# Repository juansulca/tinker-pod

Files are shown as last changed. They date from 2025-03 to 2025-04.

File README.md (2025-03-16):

# TinkerPod

Open-Source | DIY | Multitool | Modular | Extendable

The TinkerPod is an Open-Source hardware platform designed to appeal to makers, creative coders,
and designers by providing a hackable and customizable hardware. Inspired by the evolution of
multitools and influenced by contemporary devices like the Flipper Zero and SQRT,
this project explores the application of critical making, and personal fabrication to Open-Source hardware.
The TinkerPod is an ideal hardware platform for designers and makers to explore, learn, modify and extend; make it your own!

## Versions

The TinkerPod was designed to have 3 versions. All the versions are currently supported.
The main difference between versions is the parts list, complexity of assembly and features.

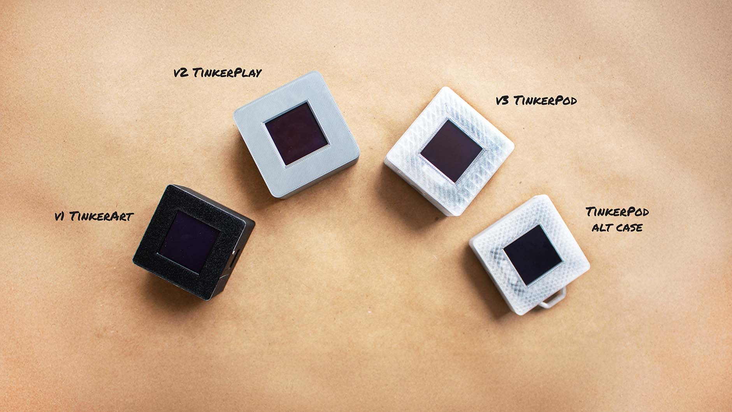
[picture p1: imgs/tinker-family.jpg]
Tinkerpod family photo


- [v1 TinkerArt](v1/): This version offers generative art functionality and can be programmed to create unique art pieces.
- [v2 TinkerPlay](v2/): This version offers a variety of games and functions, including games like pong, a timer, an etch-a-sketch inspired drawing function
  and a generative art function out of the box.
- [v3 TinkerPod](v3/): This version is an enhanced version of v2, running the same firmware but with additional features like a vibratioin sensor,
  hardware debouncing for the buttons and a fully integrated PCB.

## Hardware

This project was designed to work around the QT PY RP2040 from Adafruit. Despite this, it is possible to run the TinkerPod with
other microcontrollers with the same pinout and form factor from other manufacturers. This includes other boards from
Adafruit (QT PY line), the XIAO boards from Seeed Studio, among others.

TinkerPod v1, does not include a PCB and can be wired without tools using a tiny solderless breadboard, the display, microcontroller, and the case.

For ease of assembly starting from V2, the Screen for the TinkerPod is a 1.5" grayscale OLED display with the SSD1327 controller using a STEMMA cable. This display can be found from Adafruit and
other manufacturers but the Adafruit version is recommended due to the STEMMA cable, that reduces complexity for the assembly.

The TinkerPod v2 and v3 include PCB designs and schematics and require soldering.
A detailed assembly guide can be found along side the version files.

The hardware for this project took inspiration from the following sources:

- [Adafruit Charger BFF for QT Py](https://github.com/adafruit/Adafruit-Charger-BFF-PCB?tab=readme-ov-file#adafruit-charger-bff-for-qt-py-pcb)
- [Soldered Inkplate 2](https://github.com/SolderedElectronics/Soldered-Inkplate-2-hardware-design/tree/main)

## Firmware

All versions of the TinkerPod run on CircuitPython. The included firmware includes assets and base functionality.
You can modify the the firmware and add or change the functionality of the TinkerPod.

If you want to get started writing your own firmware and functionality, you can start with the [examples](examples/) directory.
This will provide the bassis for modifying the firmware and adding new functionality.

## Case

The case for the TinkerPod designed for 3D printing and can be printed using any FDM printer.
Printing settings are provided with each version files.

The cases for all versions were tested and printed using PLA and PETG. With the best results being
achieved with PETG on a textured plate.

Alternative cases can be found in the variants directory.

## Documentation

General guides can be found in the [docs](docs/) directory, including a simple guide to install CircuitPython and
managing the dependencies for the firmware.

## Acknowledgements

The hardware for this project took inspiration from the following sources:

- [Adafruit Charger BFF for QT Py](https://github.com/adafruit/Adafruit-Charger-BFF-PCB)
- [Soldered Inkplate 2](https://github.com/SolderedElectronics/Soldered-Inkplate-2-hardware-design/tree/main)
- [SQRT](https://ksawerykomputery.com/works/sqrt)
- [Button debounce article](https://hackaday.com/2015/12/09/embed-with-elliot-debounce-your-noisy-buttons-part-i/)

## Contributions

Contributions are welcome and appreciated. If you have any suggestions or improvements, please feel free to open an issue or submit a pull request.

## License

The TinkerPod is licensed under the following terms:

- Software: MIT License (see [LICENSE](LICENSE))
- Hardware: CERN Open Hardware Licence Version 2 - Permissive (see [LICENSE_OHL](LICENSE_OHL))
- Documentation: CC-BY-SA-4.0 (see [LICENSE_CC](LICENSE_CC))

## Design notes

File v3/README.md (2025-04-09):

# TinkerPod v3 (latest)

The latest evolution of TinkerPod delivers enhanced functionality and streamlined design through single-PCB integration. This version builds upon its predecessors, offering improved features and more robust implementation while maintaining the platform's core functionality.

The CAD and productions files for v3 con be found in the [hardware](hardware/) directory. Which is devided in:

- PCB
  - Schematic
  - PCB Layout
  - Bill of Materials
  - Gerber Files
- Case
  - Case Design
  - 3D models

The assembly instruction can be found on this page.

## v3 PCB

### Bill Of Materials

| Qty | Value | Package | Designator | Part number |
| :-- | --- | --- | --- | --- |
| 4 | .1uF, ceramic, 25V, 10%, X5R | 1210 | C1, C2, C3, C4 | KEMET - C1210X104K1RACTU |
| 2 | 10uF, ceramic, 16V, 10%, X5R | 1210 | C5, C6 | KEMET - C1210C106K3RACAUTO |
| 1 | LED | 1206 | D1 | Broadcom - HSMG-C150 |
| 1 | Schottky Diodes, 1A, 20V | SOD-123 | D2 | onsemi - MBR120ESFT1G |
| 1 | B2B-PH-SM4-TB | B2BPHSM4TBLFSN | J1 | JST - B2BPHSM4TBLFSN |
| 4 | 1K, 1/4W, 1% | 1206 | R1, R2, R3, R4 | Vishay / Beyschlag - MCA12060C1001FP500  |
| 2 | 5.1K, 1/4W, 0.1% | 1206 | R5, R6 | Panasonic - ERA-8ARB512V |
| 1 | MCP73831T-2ACI/OT | SOT-23-5 | U2 | Microchip Technology - MCP73831T-2ACI/OT |
| 1 | DPDT | JS202011AQN | S5 | C&K - JS202011AQN |

### Assembly

1. Secure the PCB with the TP v3 label facing up.
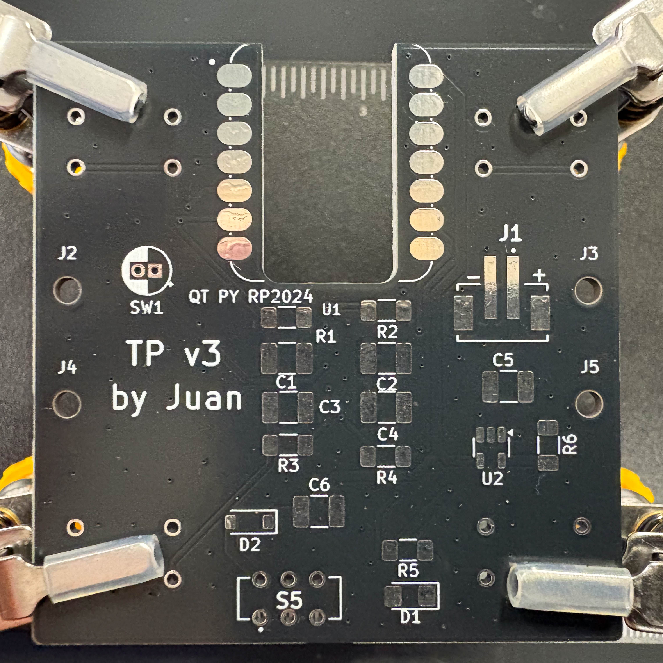
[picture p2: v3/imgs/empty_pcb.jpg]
tinkerPod PCB with label facing up
   
2. Apply paste in all the SMD pads, except for the QT PY pads, D1 and J1.
   1. Best results were achieved soldering the LED (D1) and JST (J1) connector with a soldering iron.
   2. Apply solder paste to the pads, but enough to cover the pad but not a blob bigger than the pad.
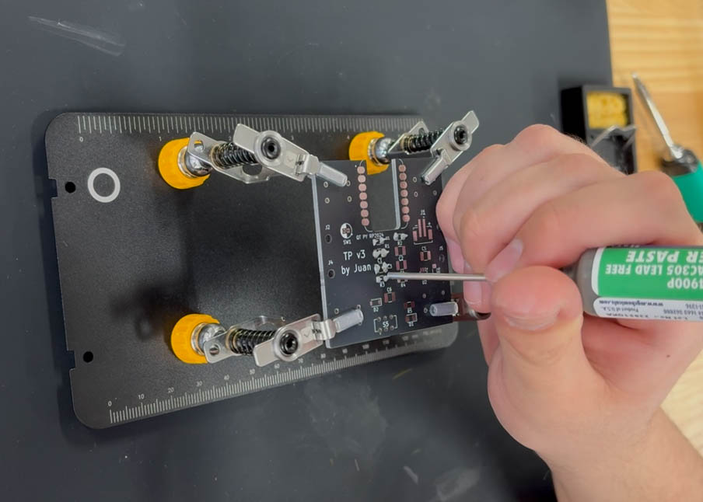
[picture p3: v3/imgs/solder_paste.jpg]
apply solder paste
      
3. Use tweezers or a tiny plastic point to remove excess solder paster.
4. Place the components that do not have polarity.
   1. Place C1, C2, C3, C4 - the .1uF capacitors.
   2. Place R1, R2, R3, R4 - 1k resistors.
   3. Place C5, C6 - 10uF capacitors.
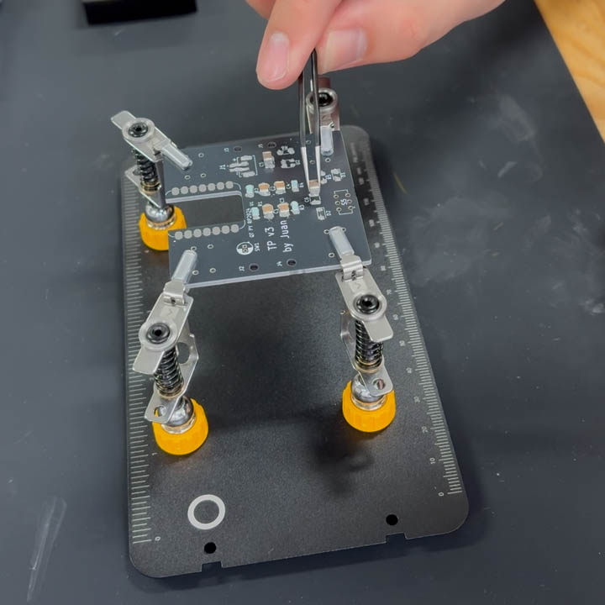
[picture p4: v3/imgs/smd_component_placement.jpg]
place smd components
      
   4. Place R5, R6 - 5.1K resistors.
5. Place the components with polarity

   1. Place D2: diode with the line facing the closed side of the rectangle
   2. Place U2: the battery charging IC

      1. The side with 3 legs should match the side with the tiny arrow

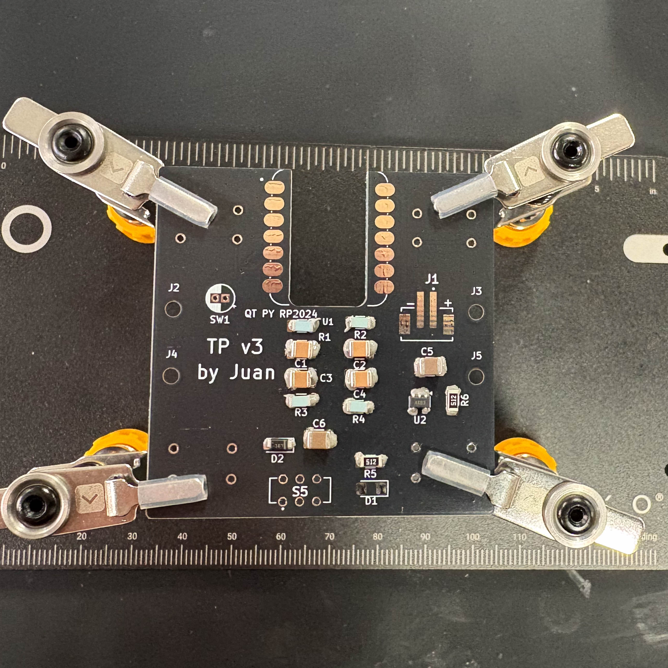
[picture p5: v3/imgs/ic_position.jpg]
battery charging IC position
      

6. Solder the components using a hot air reflow station.
   1. According to the specification of the solder paste, set the temperature, starts from the lowest recommended temperature.
   2. Start from far away with a medium to low airflow.
   3. Approach the individual components and make sure they fall correctly into place.
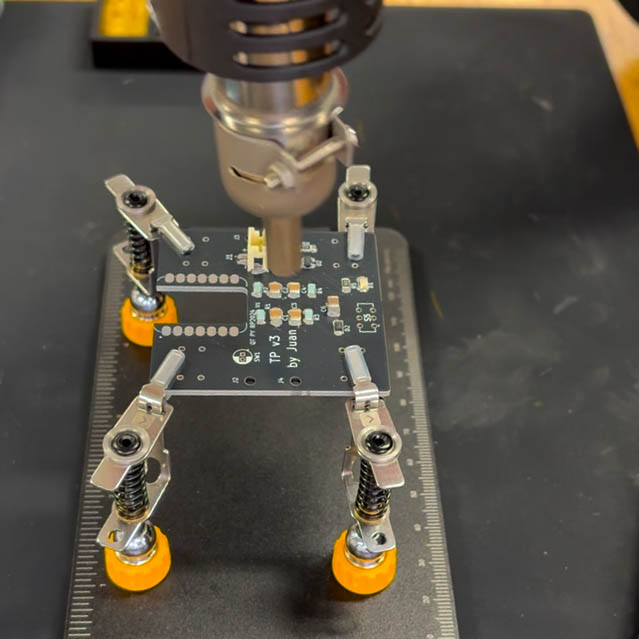
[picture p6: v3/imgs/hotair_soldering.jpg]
hot air station soldering
      
   4. After all components are soldered, visually inspect the joints, make sure the are no pads shorting and that all the paste melted. Be careful, the PCB might be hot
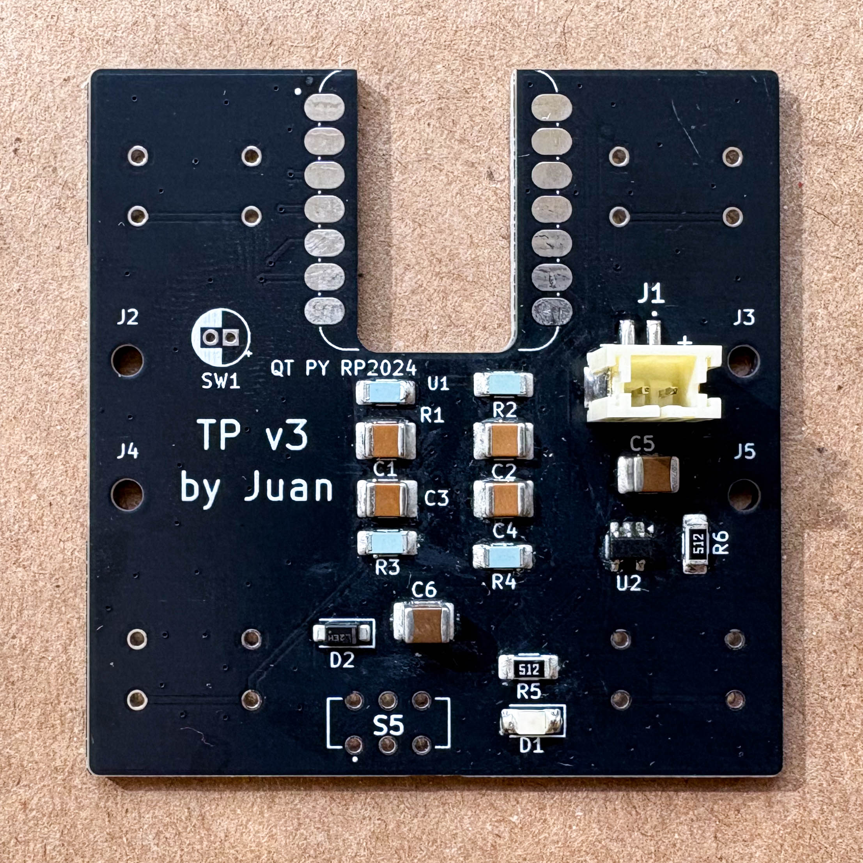
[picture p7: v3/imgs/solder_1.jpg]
PCB reference
      
   5. If there are shorting pads, retouch them with a soldering iron and some flux.
7. Solder D1 LED
   1. Check the polarity of the LED
   2. Place the LED with the Cathode (-) towards the closed side of the rectangle
   3. With the help of tweezers , solder the LED in place with a soldering iron.
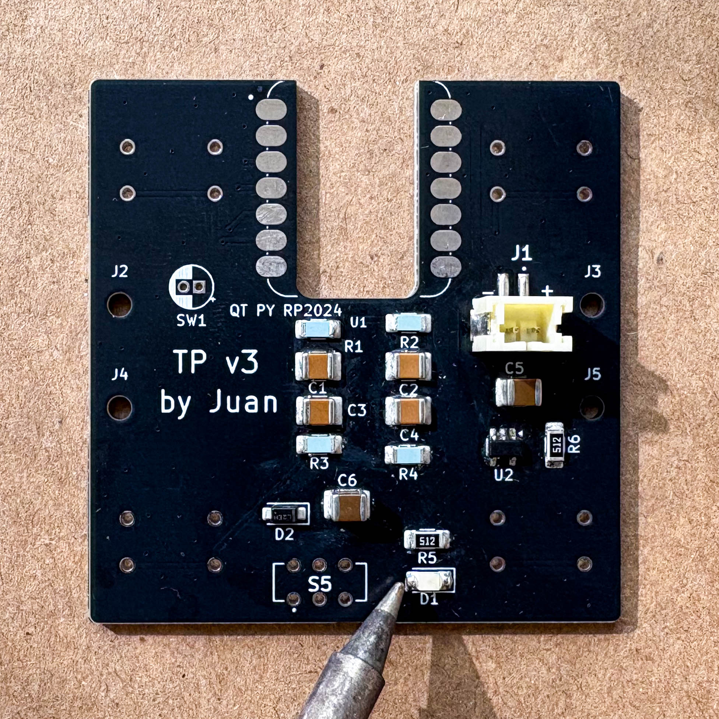
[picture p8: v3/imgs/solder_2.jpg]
Solder LED
      
8. Solder J1 JST connector.
   1. Apply some flux on the pads.
   2. Place the JST connector in place, aligning the box with the body of the connector.
   3. With the soldering iron carefully solder one of the legs of the connector.
   4. Solder the remaining legs, not much solder is needed.
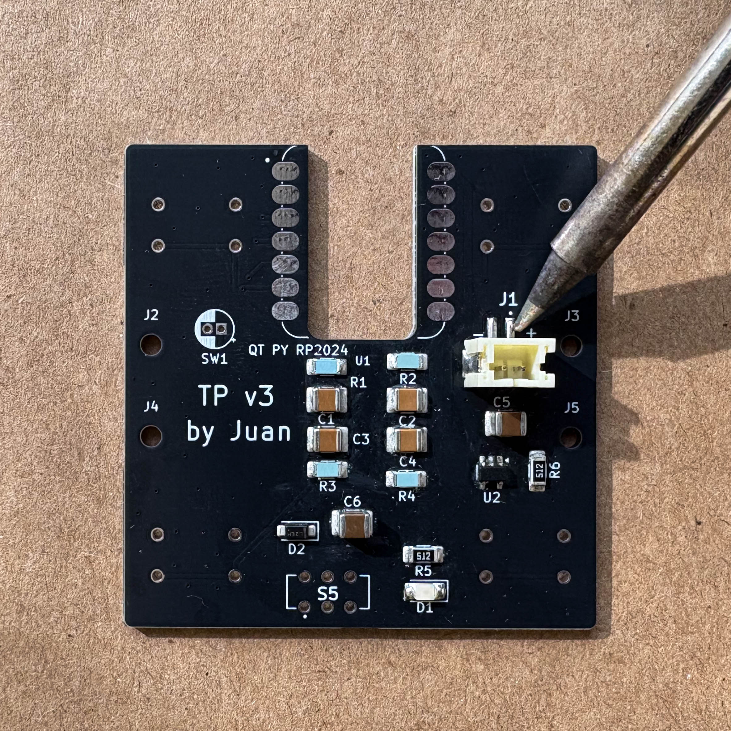
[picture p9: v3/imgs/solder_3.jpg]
Solder connector
      
9. Solder the S5 slide switch.
   1. Place the switch from the side. (TP v3 side)
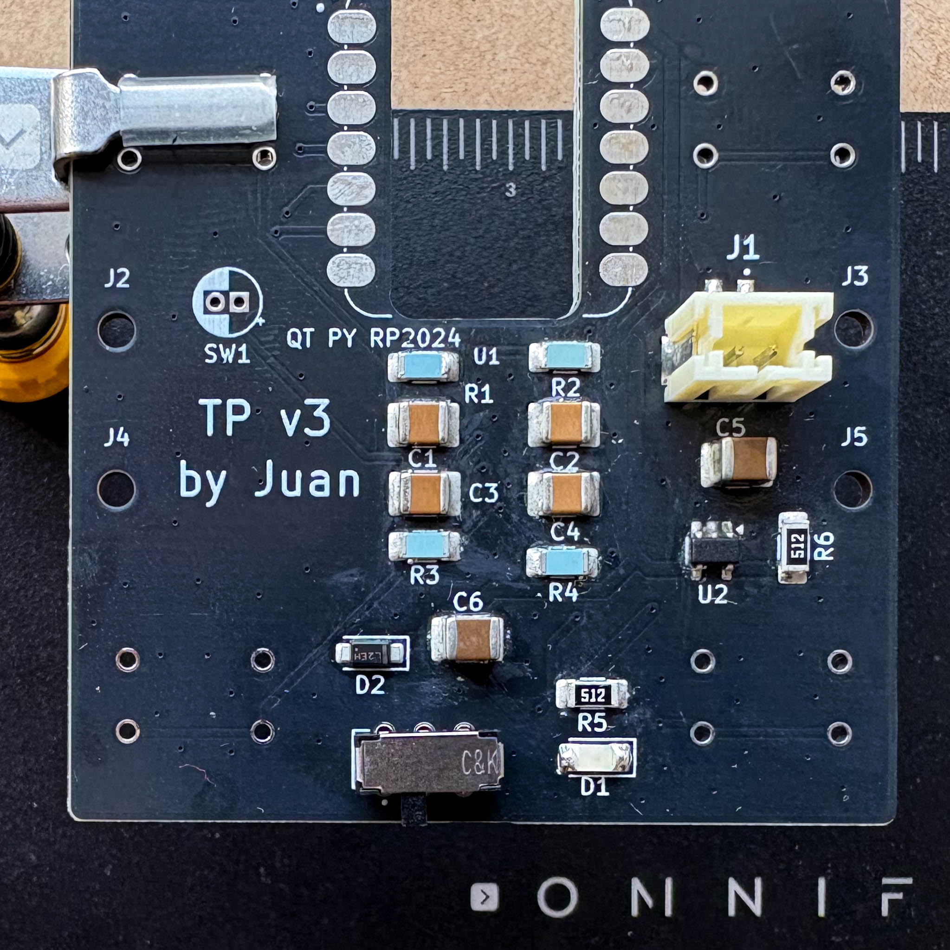
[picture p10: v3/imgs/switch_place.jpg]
placing switch
      
   2. Flip The PCB (Tinkerpod pixelated logo up)
   3. Solder the six pins.
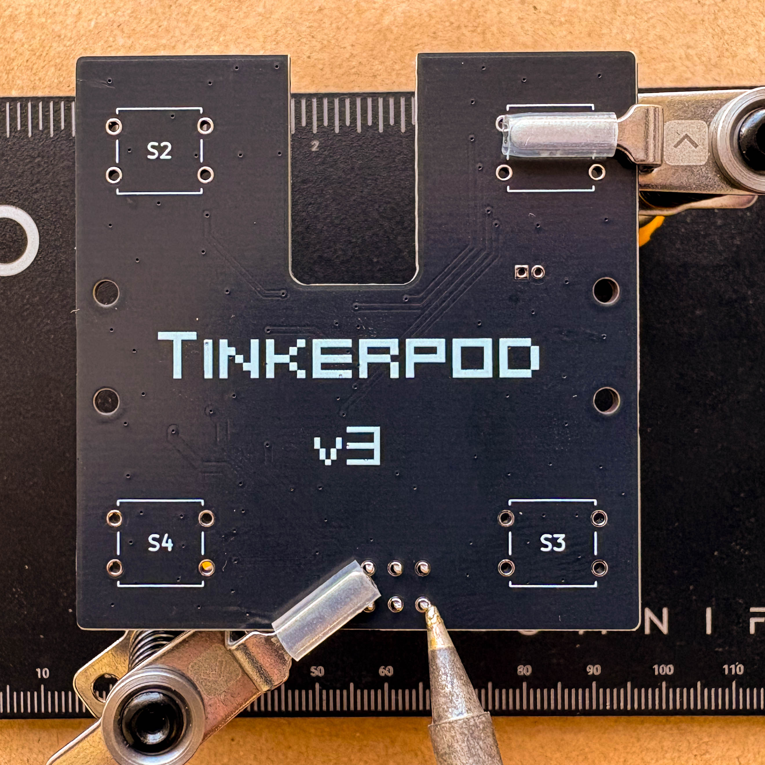
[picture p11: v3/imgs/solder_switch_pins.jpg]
Solder solder switch
      
10. The PCB assembly will continue in the next section.

## Parts List

| Item | Quantity | Description |
| --- | --- | --- |
| Adafruit QT PY RP2040 | 1 | Can be replaced with XIAO pinout boards |
| Adafruit 1.5" Gray scale OLED | 1 | SSD1327 driver chip, SPI/I2C interface  |
| TinkerPod v3 PCB | 1 | |
| STEMMA QT/Qwiic cable | 1 | 50mm long |
| Push buttons | 4 | 8mm rubber dome push buttons |
| Threaded Inserts | 8 | |
| M2 machine screws | 8 | M2 size bolts (4mm x2, 6mm x6) |
| TinkerPod v2 3D printed case  | 1 | |

## Assembly

1. Flash circuit python on the QT PY RP2040.
   1. Open the official [site](https://circuitpython.org/board/adafruit_qtpy_rp2040/) and download the latest version of circuit python.
   2. While holding the _boot_ button in the QT PY, plug it into a computer using the USB-C cable. Different version of the QT PY might need a different button to access bootloader mode, please check the official [docs](https://learn.adafruit.com/welcome-to-circuitpython/installing-circuitpython) for the specific board.
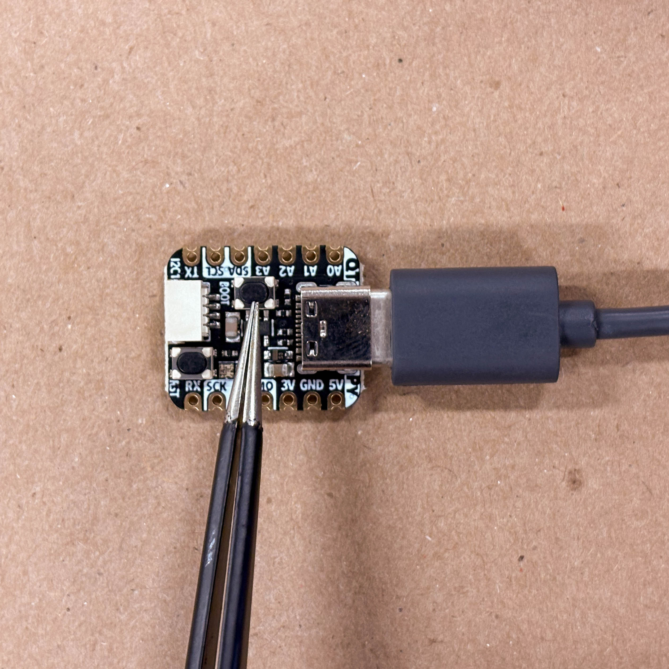
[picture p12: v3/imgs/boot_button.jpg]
boot button location
      
   3. The device should appears mounted in the OS as **RPI-RP2**, this might be different for other boards other than the RP2040 board.
   4. Drag and drop the `.UF2` file (downloaded in step 1) to the `RPI-RP2` boot drive.
   5. After a couple of seconds the onboard neopixel (LED) will flash and a new drive will appear in the computer, this time it should be called **CIRCUITPY**.
   6. ⚠️ Always eject the device before unplugging the cable.
2. Solder the QT PY to the PCB.
   1. Place the PCB with the pixelated Tinkerpod logo facing down. The **TP v3** should be visible.
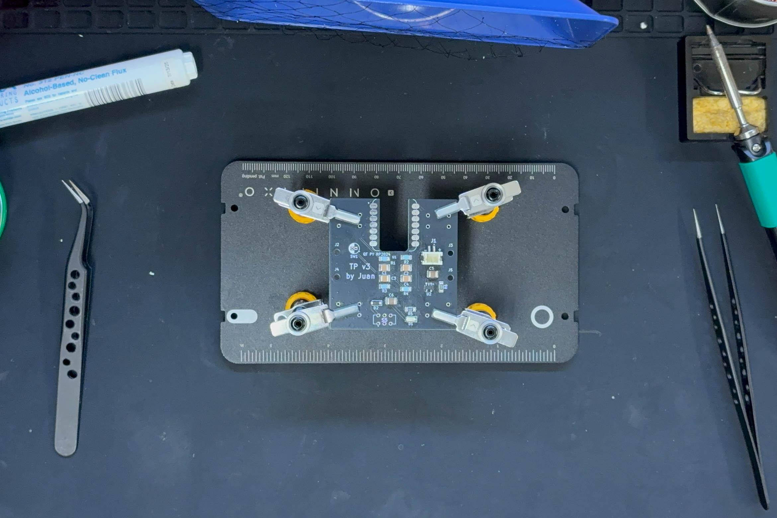
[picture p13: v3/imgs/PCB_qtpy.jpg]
Place qtpy on the PCB
      
   2. Carefully line up the QT PY with the PCB, in the `QT PY RP2040` space. The pads can be identified for the cutout in the middle. Make sure the USB port is pointing towards the outside of the board and the reset and boot buttons and the STEMMA connector are accessible.
   3. Solder the **14** pins, 7 on each side.
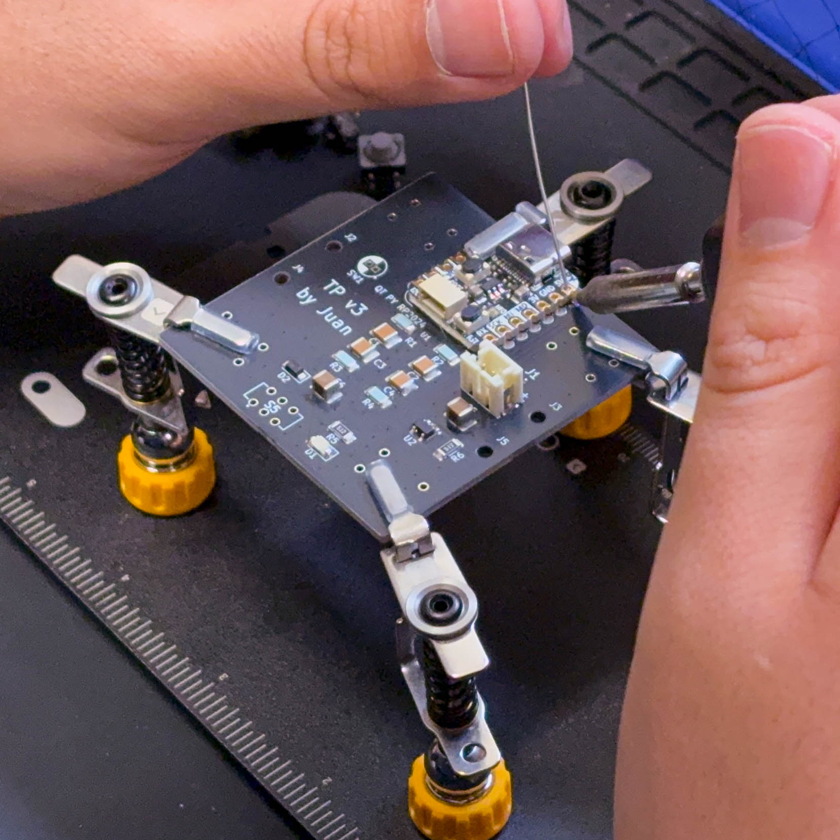
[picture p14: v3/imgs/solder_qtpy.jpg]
Solder QT PY pins
      
3. Solder the 4 buttons to the PCB.
   1. Flip the PCB (pixelated TinkerPod logo facing up).
   2. Place the buttons in the markers SW1, SW2, SW3, SW4.
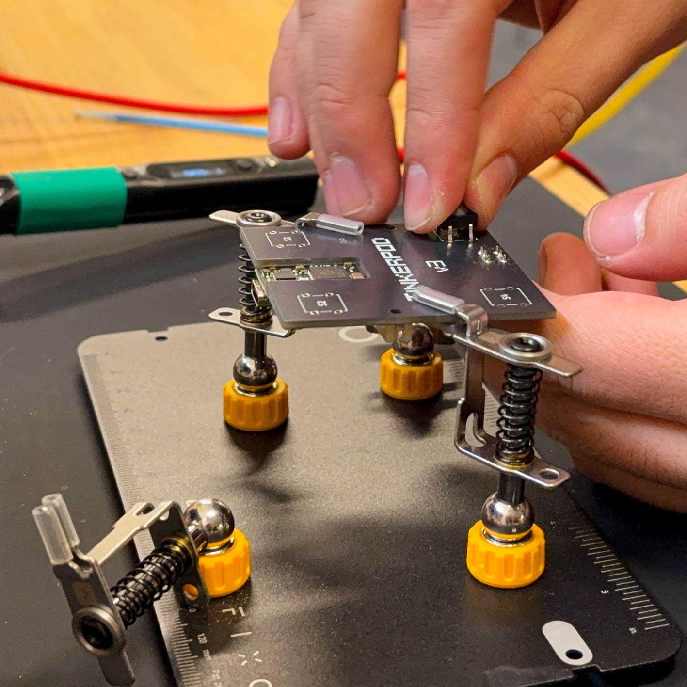
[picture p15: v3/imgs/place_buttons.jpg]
Place buttons on PCB
      
   3. Flip the PCB again (pixelated Tinkerpod logo facing down).
   4. Solder all 4 pins of every push button. (16 solder joins in total).
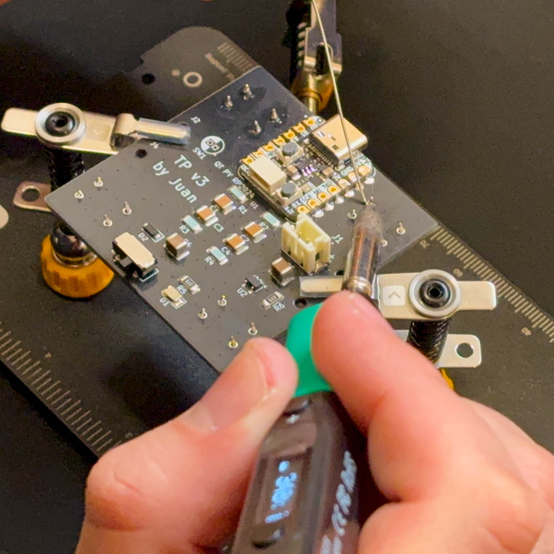
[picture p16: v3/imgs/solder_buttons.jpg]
Solder buttons pins
      
4. Solder the vibration sensor
   1. Bend the vibration sensor legs to 90 degrees.
   2. Put the vibration sensor into the SW1 slot. The vibration sensor does not have polarity.
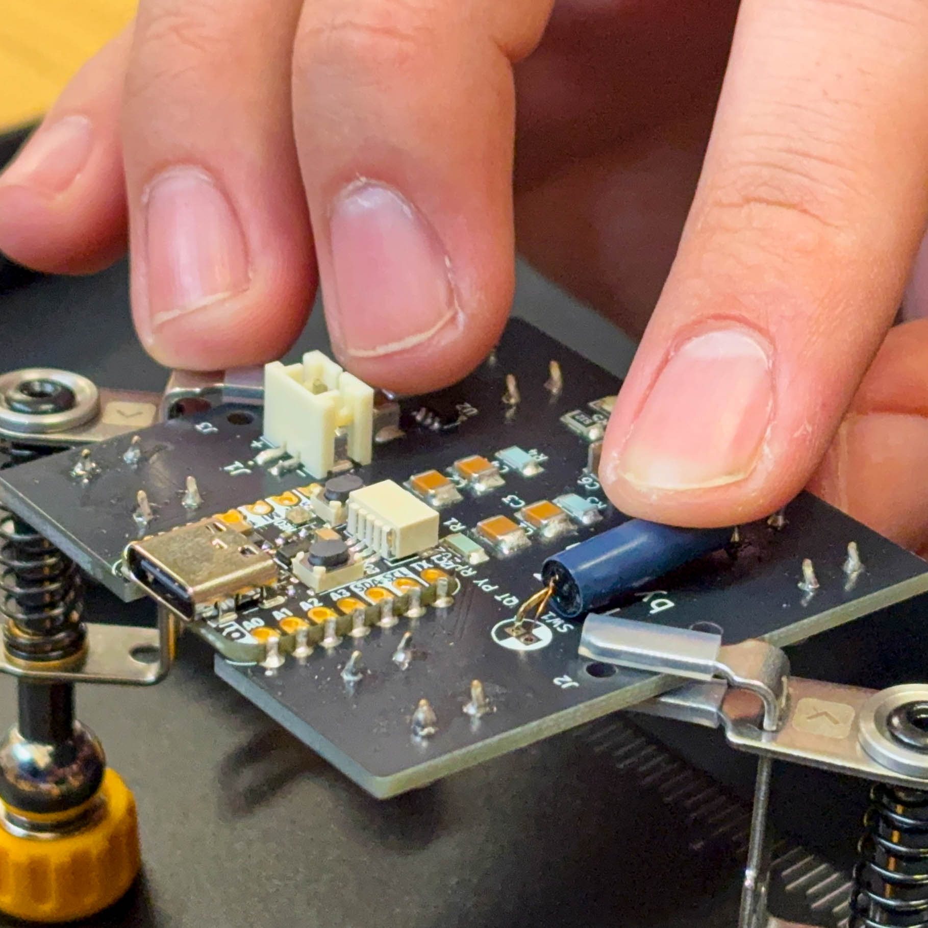
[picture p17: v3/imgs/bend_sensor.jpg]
Vibration sensor in place
      
   3. If needed use some tape to secure the vibration sensor in place while soldering.
   4. Flip the PCB (Tinkerpod logo up)
   5. Solder the two pins.
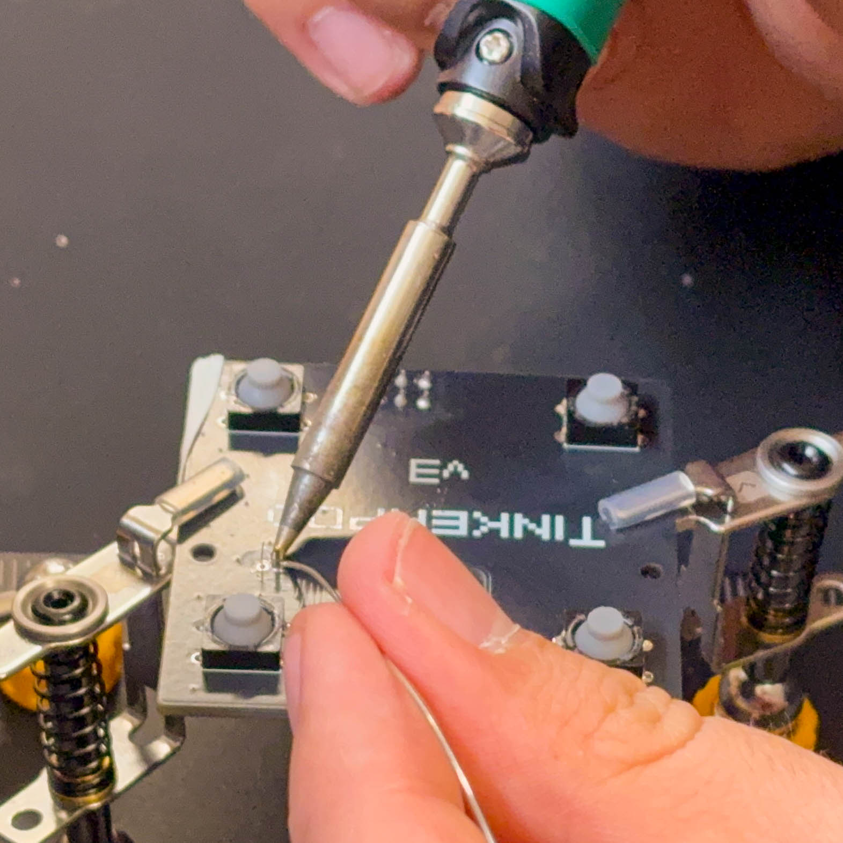
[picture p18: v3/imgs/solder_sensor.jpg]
Solder vibration sensor pins
      
   6. If the pins seem a bit long, cut them with a pair of flush cutters.
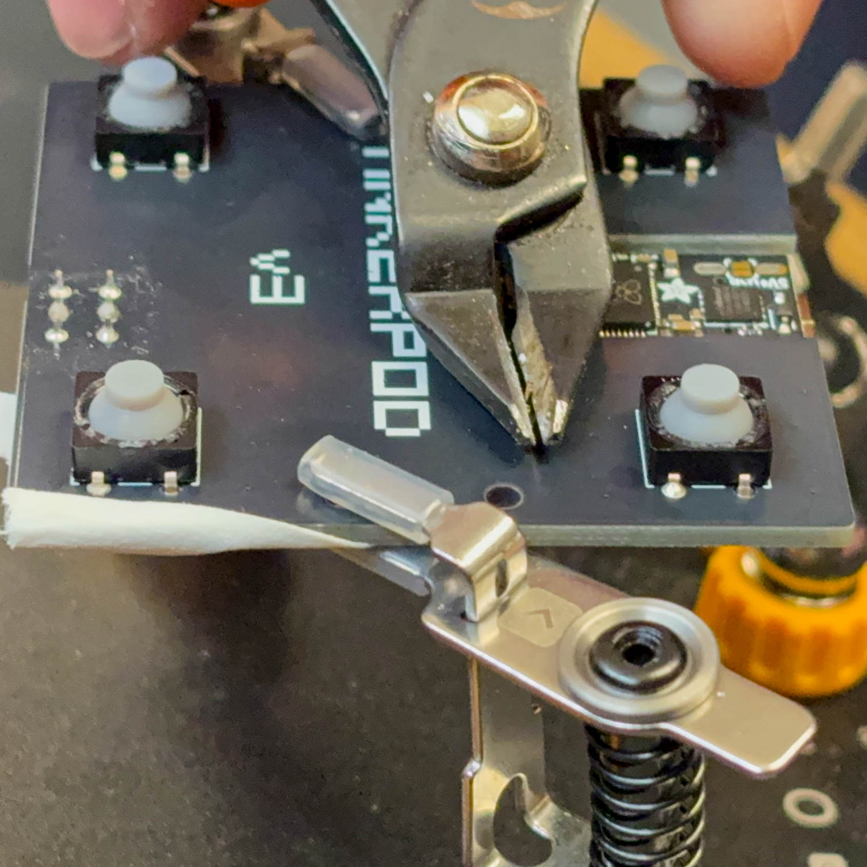
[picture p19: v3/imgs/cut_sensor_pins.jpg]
Cut sensor pins
      
5. Now is a great moment to flash firmware and test the TinkerPod before installing it into the case.
   1. Connect the STEMMA connector to the QT PY and Screen. It should slide in place without force.
   2. (Optional) Connect the battery using the JST connector in the BFF board.
   3. Download any of the TinkerPod examples from GitHub. (examples folder)
   4. Using a USB C data cable. Plug the device to the computer.
   5. Copy the content of the firmware folder (where the `code.py`file is) to the device.
   6. Do not forget to copy the `lib`directory.
   7. Alternatively install the dependencies for the firmware using `circup`.
   8. The splash screen followed by the menu should appear. Navigate the menu and use the applications by pressing the 4 buttons.
   9. A green LED should be _on_ if there is battery connected to the JST terminal.
   10. If everything works as expected, continue with the next step. If something is not working, check for cold solder joins and check that that the firmware was flashed correctly. If there is red LED flashing there is an issue with the firmware.
   11. Eject the device and unplug the USB cable.
6. Prepare the bottom case.
   1. Slide the battery bracket on the PCB.
   2. Place the PCB in place (with the USB-C port towards the hole in the enclosure) and screw it in place using the M2 machine screws.
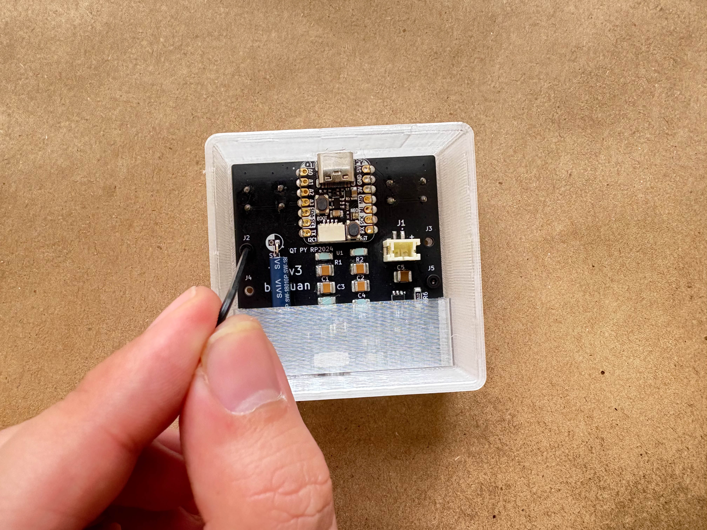
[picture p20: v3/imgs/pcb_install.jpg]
PCB installation
      
   3. Push the 3D printed on/off switch and make sure the power switch is in the _off_ position (right side).
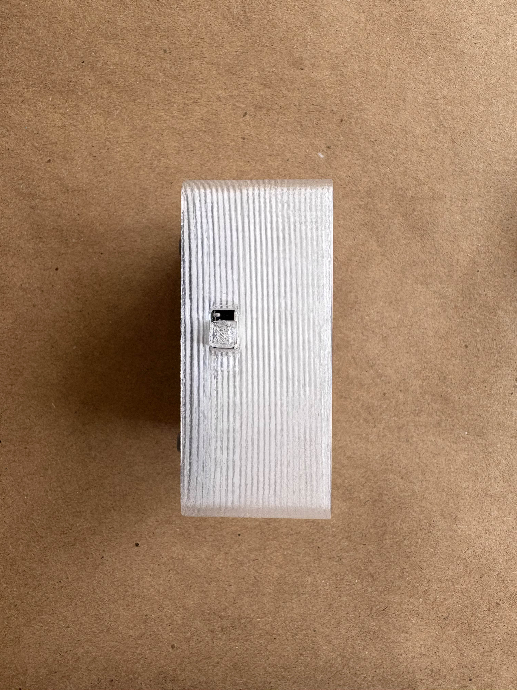
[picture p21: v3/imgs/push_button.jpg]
Push 3D printed button in place
      
7. Prepare the screen assembly
   1. Connect the STEMMA cable into the screen, it should slide in place without force.
   2. Gently place the 1.5" screen into the slot, do not apply pressure on the screen.
   3. Place the screen supports and line up the holes. The rectangular piece should go towards the top (can be placed in any orientation) and the remaining piece should go to the bottom. The bottom piece will only line up one way, with the legs pointing to the top.
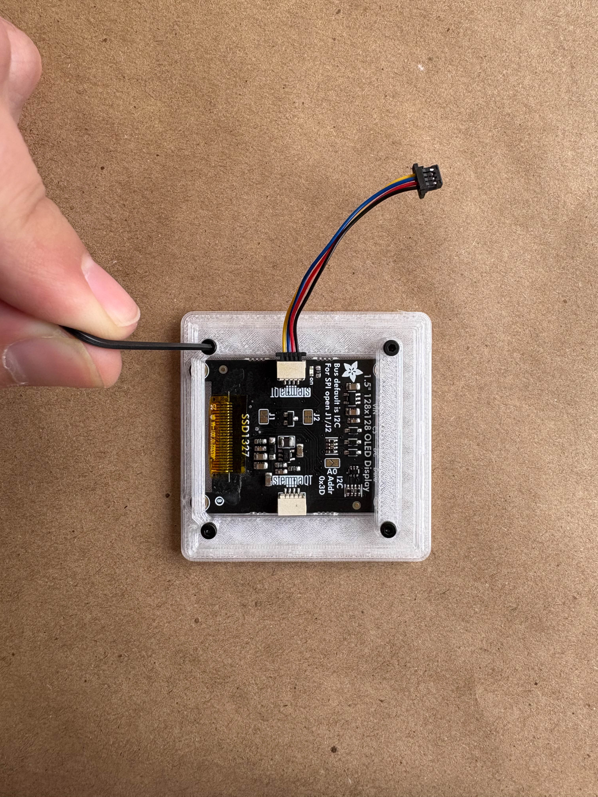
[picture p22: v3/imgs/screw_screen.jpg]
Screw screen supports in place
      
   4. Screw the supports to the top enclosure, tighten the screws until there is some resistance. Do not over tighten the screws.
   5. The screen might have some play, this is expected. And some gaps might be visible from the front side, which is also expected.
8. Closing the enclosure.
   1. Plug the other side of the STEMMA connector to the QT PY.
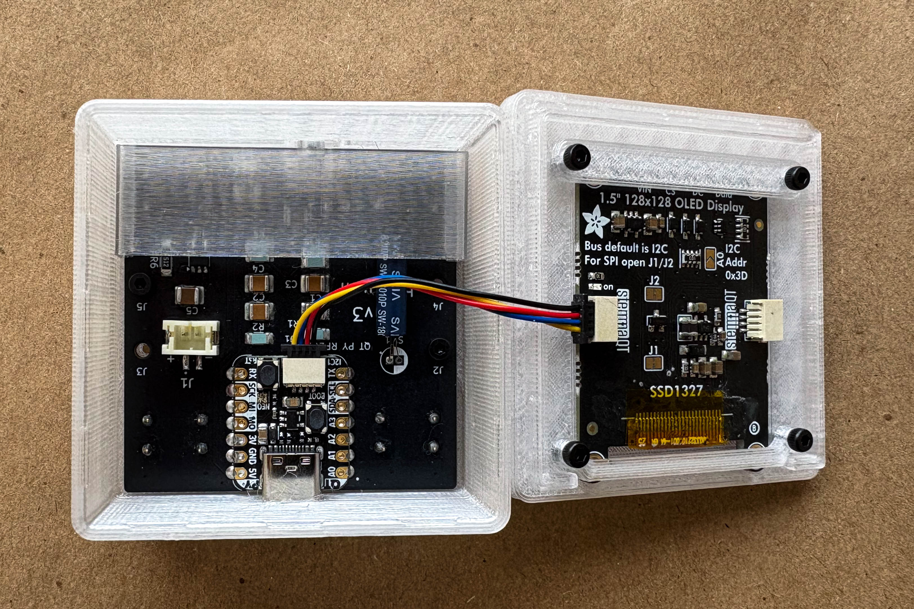
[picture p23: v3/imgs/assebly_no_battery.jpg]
Plug in STEMMA connector
      
   2. Plug in the battery.
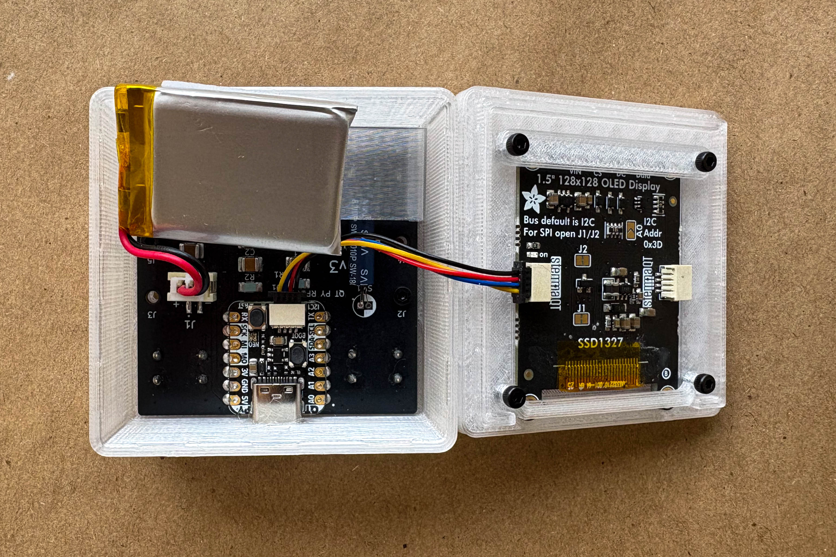
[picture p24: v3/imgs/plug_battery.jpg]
Plug in the battery
      
   3. Secure the battery using the battery bracket and some double-sided tape.
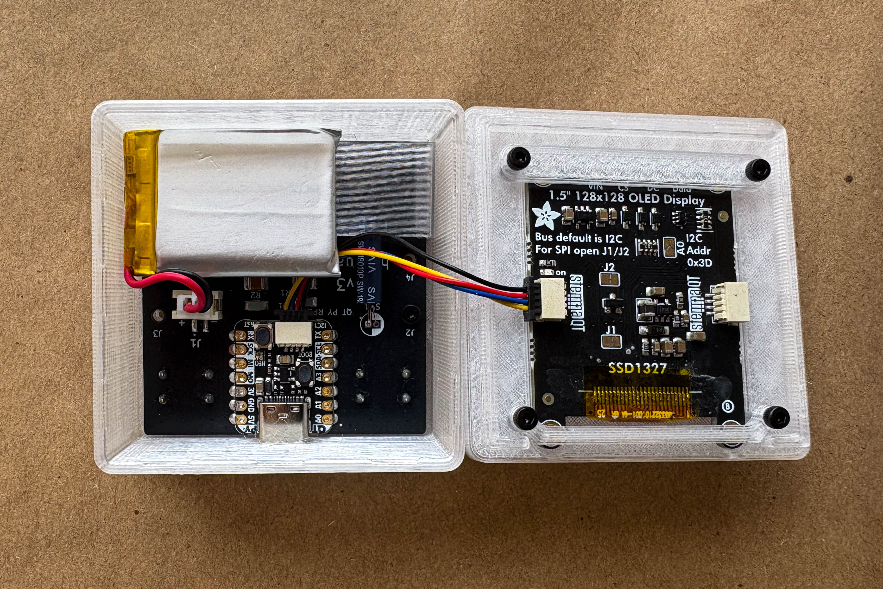
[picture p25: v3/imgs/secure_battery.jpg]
Secure battery with double sided tape
      
   4. Close the enclosure
9. Turn on your device
10. Happy Tinkering!
    Final device

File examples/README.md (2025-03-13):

# Tinker pod examples

## Introduction

This repository contains examples of using the Tinker pod in various scenarios.
Each example is designed to demonstrate a specific feature or functionality of the Tinker pod.
All these examples are related to the implementation of the Tinker pod firmware. By following these examples,
you can learn the basics of the Tinker pod to create interactive and dynamic applications.

## Structure

- **examples/**: This directory contains various examples demonstrating the usage of the Tinker pod.
  Each directory contains a README.md file that explains the purpose of the example and provides instructions on how to run it,
  the dependencies required to run the example, and the schematic.

- Start with the [screen](screen/) example, that goes over a simple screen setup and displaying text.
- The [button](button/) example, a button for the tinker pod is set up and button event handling is demonstrated.
- The [draw](draw/) example, showcase how to setup a canvas and programatically draw on the screen.
- The [animation](animation/) example, demonstrate how to move elements on the screen every frame.

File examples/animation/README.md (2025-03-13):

# Animation Example

For this example, you can use the tinker pod v2 or v3 PCB or the breadboard option from v1.

## Parts

| Part | Quantity |
| --- | --- |
| Adafruit QT PY RP2040 | 1 |
| 1.5" Gray scale OLED | 1 |
| STEMMA QT/Qwiic cable | 1 |
| Tiny breadboard (Optional) | 1 |

## Schematic

Gently connect the STEMMA QT/Qwiic cable to the Adafruit QT PY RP2040 and the 1.5" Gray scale OLED.

> Optionally you can follow the wiring diagram from v1 to use a waveshare screen.

Wiring Diagram

## Flashing CircuitPython

If you have not already installed CircuitPython, follow the guide found [here](/docs/install-circuitpython.md)

## Dependencies

Ensure this dependencies are present in the `lib` folder on the microcontroller:

- Adafruit CircuitPython firmware for the supported boards:
  https://github.com/adafruit/circuitpython/releases
- Adafruit CircuitPython SSD1327 driver:
  https://github.com/adafruit/Adafruit_CircuitPython_SSD1327
- Adafruit CircuitPython Display Text library:
  https://github.com/adafruit/Adafruit_CircuitPython_Display_Shapes

A tutorial for installing dependencies can be found [here](/docs/install-dependencies.md)

## Running the example

To run the example, follow these steps:

1. Connect the microcontroller to a computer using a USB-C cable.
2. Copye the `code.py` file from this folder to the `CIRCUITPY` drive.
3. The QT PY should soft reboot and run the code.

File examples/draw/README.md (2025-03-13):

# Draw Example

For this example, you can use the tinker pod v2 or v3 PCB or the breadboard option from v1.

## Parts

| Part | Quantity |
| --- | --- |
| Adafruit QT PY RP2040 | 1 |
| 1.5" Gray scale OLED | 1 |
| STEMMA QT/Qwiic cable | 1 |
| Tiny breadboard (Optional) | 1 |

## Schematic

Gently connect the STEMMA QT/Qwiic cable to the Adafruit QT PY RP2040 and the 1.5" Gray scale OLED.

> Optionally you can follow the wiring diagram from v1 to use a waveshare screen.

Wiring Diagram

## Flashing CircuitPython

If you have not already installed CircuitPython, follow the guide found [here](/docs/install-circuitpython.md)

## Dependencies

Ensure this dependencies are present in the `lib` folder on the microcontroller:

- Adafruit CircuitPython firmware for the supported boards:
  https://github.com/adafruit/circuitpython/releases
- Adafruit CircuitPython SSD1327 driver:
  https://github.com/adafruit/Adafruit_CircuitPython_SSD1327

A tutorial for installing dependencies can be found [here](/docs/install-dependencies.md)

## Running the example

To run the example, follow these steps:

1. Connect the microcontroller to a computer using a USB-C cable.
2. Copye the `code.py` file from this folder to the `CIRCUITPY` drive.
3. The QT PY should soft reboot and run the code.

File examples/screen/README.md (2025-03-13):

# Screen Example

For this example, you can use the tinker pod v2 or v3 PCB or the breadboard option from v1.

## Parts

| Part | Quantity |
| --- | --- |
| Adafruit QT PY RP2040 | 1 |
| 1.5" Gray scale OLED | 1 |
| STEMMA QT/Qwiic cable | 1 |
| Tiny breadboard (Optional) | 1 |

## Schematic

Gently connect the STEMMA QT/Qwiic cable to the Adafruit QT PY RP2040 and the 1.5" Gray scale OLED.

> Optionally you can follow the wiring diagram from v1 to use a waveshare screen.

Wiring Diagram

## Flashing CircuitPython

If you have not already installed CircuitPython, follow the guide found [here](/docs/install-circuitpython.md)

## Dependencies

Ensure this dependencies are present in the `lib` folder on your microcontroller:

- Adafruit CircuitPython firmware for the supported boards:
  https://github.com/adafruit/circuitpython/releases
- Adafruit CircuitPython SSD1327 driver:
  https://github.com/adafruit/Adafruit_CircuitPython_SSD1327
- Adafruit CircuitPython Display Text library:
  https://github.com/adafruit/Adafruit_CircuitPython_Display_Text

A tutorial for installing dependencies can be found [here](/docs/install-dependencies.md)

## Running the example

To run the example, follow these steps:

1. Connect the microcontroller to a computer using a USB-C cable.
2. Copye the `code.py` file from this folder to the `CIRCUITPY` drive.
3. The QT PY should soft reboot and run the code.

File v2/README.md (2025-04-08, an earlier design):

# TinkerPod v2

TinkerPod v2 is a more advanced version of the tinkerpod. This version includes 4 buttons and an optional LiIon charger and battery.
This version can be powered using a USB-C cable with a powerbank, phone or USB-C charger.
The firmware included with this version includes more applications and a application menu.

## Parts List

| Item | Quantity | Description |
| --- | --- | --- |
| Adafruit QT PY RP2040 | 1 | Can be replaced with XIAO pinout boards |
| Adafruit 1.5" Gray scale OLED | 1 | SSD1327 driver chip, SPI/I2C interface |
| TinkerPod v2 PCB | 1 | |
| STEMMA QT/Qwiic cable | 1 | 50mm long |
| Push buttons | 4 | 8mm rubber dome push buttons |
| Adafruit LiIon Charger BFF Add-On | 1 | (Optional battery powered) |
| Lithium Ion Polymer Battery | 1 | (Optional battery powered) 3.7v – 420mAh single cell |
| Threaded Inserts | 8 | |
| M2 machine screws | 8 | M2 size bolts (4mm x2, 6mm x6) |
| TinkerPod v2 3D printed case | 1 | |

## Required tools:

| Item | Description |
| --- | --- |
| Soldering Iron | Preferably one with a fine tip |
| Solder | Rosin core, preferably thin |
| Flux | Paste or pen |
| Hex key | Or screw driver depending on the screws |
| Twezzers | (optional) |
| USB-C cable | USB C **data** cable (USB C to C/A) |

## Assembly

1. Flash circuit python on the QT PY RP2040.
   1. Open the official [site](https://circuitpython.org/board/adafruit_qtpy_rp2040/) and download the latest version of CircuitPython.
   2. While holding the _boot_ button in the QT PY, plug it into a computer using the USB-C cable. Different version of the QT PY might need a different button to access bootloader mode, please check the official [docs](https://learn.adafruit.com/welcome-to-circuitpython/installing-circuitpython) for the specific board.
      boot button location
   3. The device should appears mounted in the OS as **RPI-RP2**, this might be different for other boards other than the RP2040 board.
   4. Drag and drop the `.UF2` file (downloaded in step 1) to the `RPI-RP2` boot drive.
   5. After a couple of seconds the onboard neopixel (LED) will flash and a new drive will appear in the computer, this time it should be called **CIRCUITPY**.
   6. ⚠️ Always eject the device before unplugging the cable.
2. (Optional) Solder the LiIon Charger BFF to the PCB.
   1. Place the PCB donut side down. The **TinkerPod** and **v2** silkscreen labels should be visible.
   2. Carefully line up the BFF with the PCB, in the M2 space, also marked as BFF LiPo charger. The JST connector (white box) should be facing the **v2** text on the PCB.
      bff line up
   3. Solder all the pads. take extra care on the 5V and GND pads.
      solder bff pads
3. Solder the QT PY to the PCB.
   1. Place the PCB donut side down. The **TinkerPod** and **v2** silkscreen labels should be visible.
   2. Carefully line up the QT PY with the PCB, in the `M1` space also marked on the side as `QT PY RP2040`. The pads can be identified for the cutout in the middle. Make sure the USB port is pointing towards the outside of the board and the reset and boot buttons and the STEMMA connector are accessible.
      QT PY lineup
   3. Solder the **14** pins, 7 on each side.
      QT PY solder pins
4. Solder the 4 buttons to the PCB.
   1. After completing steps 2 and 3, flip the PCB (Donut side up).
      PCB donut side up
   2. Place the buttons in the markers SW1, SW2, SW3, SW4.
      button placement
   3. Flip the PCB again (Donut side down).
   4. Solder all 4 pins of every push button. (16 solder joins in total).
      solder pins for button
5. Now is a great moment to flash the firmware and test the TinkerPod before installing it into the case.
   1. Connect the STEMMA connector to the QT PY and Screen. It should slide in place without force.
      connect STEMMA connector to QT PY
   2. (Optional) Connect the battery using the JST connector in the BFF board.
      PCB with battery connected
   3. Download the TinkerPod firmware from GitHub. (firmware folder)
   4. Using a USB C data cable. Plug the device to the computer.
   5. Copy the content of the firmware folder (where the `code.py`file is) to the device.
   6. Remember to copy the `lib`directory.
   7. Alternatively check this project documentation for alternative installation methods.
   8. The splash screen followed by the menu should appear. Navigate the menu and use the applications by pressing the 4 buttons.
   9. The charging indicator (orange LED) in the BFF board should light up if there is a battery connected and the BFF installed.
      Test assembly with orange LED on and text on the screen
   10. If everything works as expected, continue with the next step.
       1. If something is not working:
       2. Check for cold solder joins
       3. Verify that that the firmware was flashed correctly.
       4. If there is red LED flashing there is an issue with the firmware.
   11. Eject the device and unplug the USB cable.
6. Place the 3D printed buttons in the enclosure and make sure they slide smooth.
   placing buttons
7. Prepare the bottom enclosure.
   1. Place the threaded inserts in the holes located in the top part of the enclosure.
      placing inserts
   2. Using the soldering iron push the inserts as straight as possible until they are flush with the surface of the enclosure.
      push inserts with soldering iron
   3. Place the PCB in place (with the USB-C port towards the hole in the enclosure) and screw it in place using the M2 machine screws.
   4. Make sure the power switch on the BFF board is in the _off_ position.
   5. Plug in the battery.
      battery plugged in
   6. Secure the battery using the battery bracket and some double sided tape.
8. Prepare the screen assembly
   1. Place the threaded inserts in the holes located in the top part of the enclosure.
   2. Using the soldering iron push the inserts as straight as possible until they are flush with the surface of the case.
      top enclosure inserts
   3. Connect the STEMMA cable into the screen, it should slide in place without force.
   4. Gently place the 1.5" screen into the slot, do not apply pressure on the scree.
      screen in top enclosure
   5. Place the screen supports and line up the holes. The rectangular piece should go towards the top (can be placed in any orientation) and the remaining piece should go to the bottom. The bottom piece will only line up one way, with the legs pointing to the top.
   6. Screw the supports to the top case, tighten the screws until there is some resistance. Do not over tighten the screws.
      screw screen supports
   7. The screen might have some play, this is expected. And some gaps might be visible from the front side, which is also expected.
9. Closing the case.
   1. Plug the other side of the STEMMA connector to the QT PY.
      final device assembly
   2. Using the power switch in the BFF board, turn the device _on_.
   3. Gently push the two parts of the case together.
10. Happy tinkering!
    final device assembly

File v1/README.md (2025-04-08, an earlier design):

# Tinkerpod v1

The TinkerPod v1 is the simplest version of the family. It is designed to be a basic introduction to the TinkerPod ecosystem.

## Part list

| Part | Quantity |
| --- | --- |
| Adafruit QT PY RP2040 | 1 |
| 1.5" Gray scale OLED  | 1 |
| Tiny breadboard | 1 |
| Jumper wires | 5 |

## 3D Printed Case

This version was tested with PLA and PETG.
The suggested orientation of the two parts is with the flat surfaces facing the build plate.
The print was made without supports with the following params:

| Param | Value |
| --- | ----- |
| Layer height | 0.2mm |
| Nozzle | 0.4mm |
| Infill | 20% |

The STL files can be found in the [`case/`](case/) directory.

## Firmware

The current firmware consists of the screen setup and a generative art demo.
The firmware is written in CircuitPython and works
by coping the content of the [`firmware`](firmware/) directory to the microcontroller.

### Dependencies

The firmware depends on the following libraries:

- [Adafruit CircuitPython SSD1327 driver](https://github.com/adafruit/Adafruit_CircuitPython_SSD1327)

More information about this library can be found in the official [docs](https://docs.circuitpython.org/projects/ssd1327/en/latest/)

## Assembly

1. Flash circuit python on the QT PY RP2040.

   1. Open the official [site](https://circuitpython.org/board/adafruit_qtpy_rp2040/) and download the latest version of CircuitPython.
   2. While holding the _boot_ button in the QT PY, plug it into a computer using the USB-C cable. Different version of the QT PY might need a different button to access bootloader mode, please check the official [docs](https://learn.adafruit.com/welcome-to-circuitpython/installing-circuitpython) for the specific board.
      boot button location
   3. The device should appears mounted in the OS as **RPI-RP2**. This might be different for other boards other than the RP2040 board.
   4. Drag and drop the `.UF2` file (downloaded in step 1) to the `RPI-RP2` drive.
   5. After a couple of seconds the onboard neopixel (LED) will flash and a new drive will appear in the computer, this time it should be called **CIRCUITPY**.
   6. ⚠️ Always eject the device before unplugging the cable.

2. Solder the headers to the QT PY.
   1. Position the headers in the QT PY and carefully place both the breadboard.
      header positioning
   2. Solder the headers to the microcontroller.
      header soldering
3. Place the microcontroller on the breadboard and connect the screen cable to the screen socket.
   screen connector placement
4. Connect the screen to the QT PY following this diagram:
   Tinkerpod v1 wiring diagram
5. Plug the USB-C cable to the micro controller.
   microcontroller breadboard
6. Check your file explorer for new drive called CIRCUITPY
7. Download the `firmware/` directory for this version.
8. Copy all the files from the `firmware/` directory (`code.py` and `lib/`) to the **CIRCUITPY** drive.
9. After the device restarts, look at the OLED screen which will display a generative art function.
10. Place the screen in the top part of the enclosure.
    screen in top enclosure
11. Place the breadboard in the bottom part of the enclosure.
    breadboard in enclosure and screen
12. Close the enclosure with some tape.
    final

> ⚠️ Do not unplug the device from your computer without ejecting it properly.

## Official mods

### Add interaction with a vibration sensor

To add the same vibration sensor from version 2 to the TinkerPod v1.

Follow this schematic:

vibration sensor schematic

And update the `code.py` file to use the sensor following the [button example](/examples/button).

For example:

```python
# code.py in firmware

# create the digital input for the vibration sensor on Pin A1
shake = digitalio.DigitalInOut(board.A1)
shake.direction = digitalio.Direction.INPUT
# enable pull up resistor
shake.pull = digitalio.Pull.UP

# store the shake state
was_shaken = False

while(True):
	# read the shake sensor as any other button
	if not shake.value:
		# store the shake state
		was_shaken = True

	# if the device was shaken
	if was_shaken:
		# get a random quadrant
		i = random.randint(0, 15);
		# clear the space on the screen
		clear_quadrant(i)
		# get a random draw function
		fn = random.choice(fns)
		# draw the function on the screen
		fn(i)
		# clear the shaken state
		was_shaken = False
		# wait for 0.3 seconds
		time.sleep(0.3)
```

Now the tinkerpod will react to a shake by updating the screen.

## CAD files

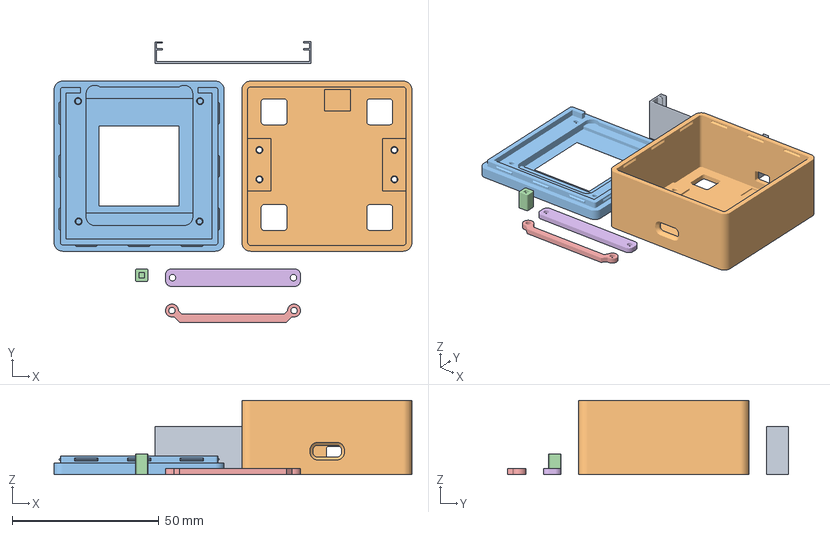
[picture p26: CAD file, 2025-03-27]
v3/case/TP_v3_case.3mf
122.0 x 95.6 x 25.2 mm
battery_bracket
lead
power_button
support_1
support_2

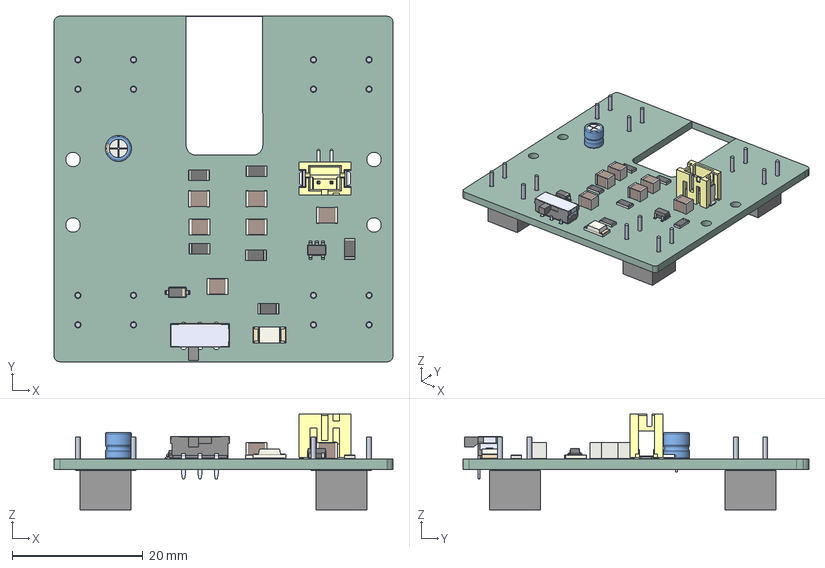
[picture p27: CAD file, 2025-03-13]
v3/hardware/tinker-pod-v3.step
51.8 x 52.8 x 14.6 mm
R_1206_3216Metric x 6
C_1210_3225Metric x 6
SOT_23_5
CP_Radial_D40mm_P150mm
LED_2010_5025Metric
D_SOD_123
JS202011AQN
B2B-PH-SM4-TB(LF)(SN)
ASSEMBLY x 4
tinker-pod-v3_PCB

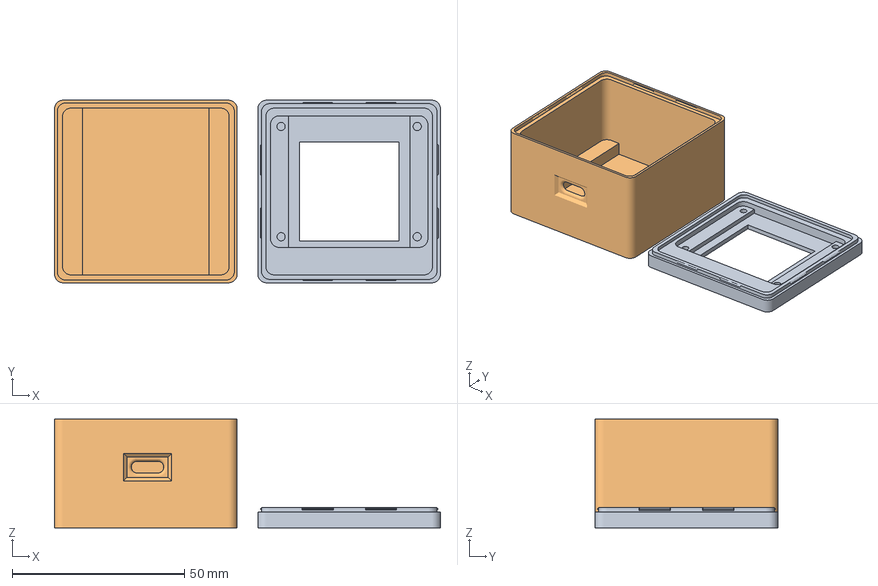
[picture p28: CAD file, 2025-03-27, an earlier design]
v1/case/TP_v1_case.3mf
112.0 x 53.0 x 31.5 mm
screen

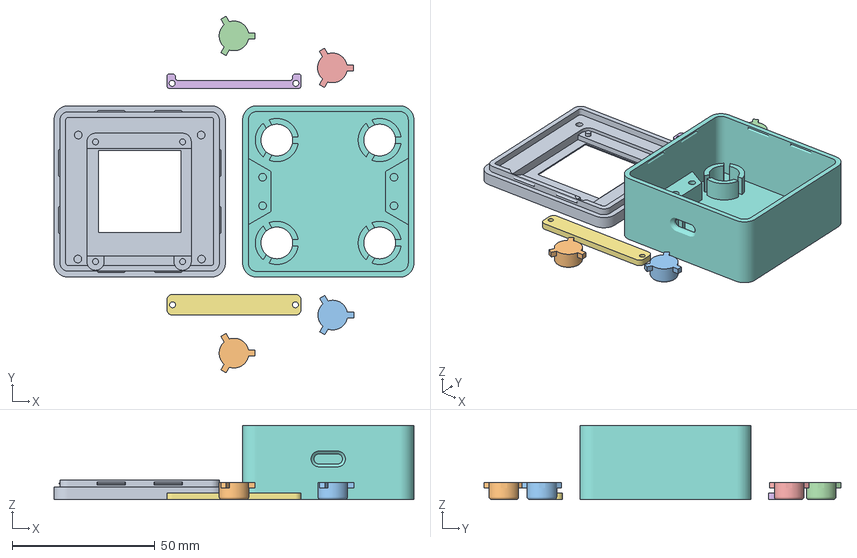
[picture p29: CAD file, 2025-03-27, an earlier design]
v2/case/TP_v2_case.3mf
126.0 x 124.8 x 26.0 mm
New_Top
Button
screen_support_1
screen_support_2
new_Bottom_v2

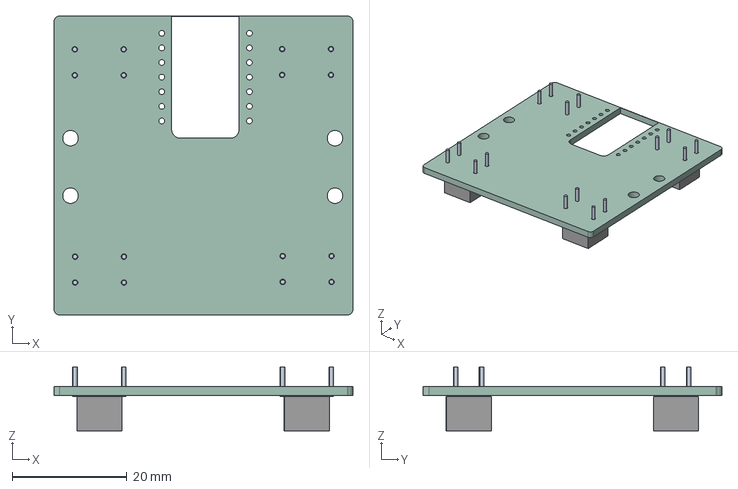
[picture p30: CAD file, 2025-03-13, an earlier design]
v2/hardware/tinker-pod-buttons.step
52.0 x 52.0 x 11.1 mm
ASSEMBLY x 4
tinker-pod-buttons_PCB

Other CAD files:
v1/case/TinkerPod_v1_case.f3d
v2/case/TP_v2_case.f3z
v3/case/TP_v3_case.f3z

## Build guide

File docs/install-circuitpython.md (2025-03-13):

# How to Install CircuitPython on Adafruit QT PY RP2040

To flash CircuitPython onto your Adafruit QT PY RP2040, follow these steps:

1. Open the official [site](https://circuitpython.org/board/adafruit_qtpy_rp2040/) and download the latest version of circuit python.
2. While holding the _boot_ button in you QT PY, plug it into your computer using the USB-C cable.
   Different version of the QT PY (the non-RP2040 variants) might need a different button to access bootloader mode,
   please check the official [docs](https://learn.adafruit.com/welcome-to-circuitpython/installing-circuitpython) for the board you are using.
3. The device should appears mounted in your OS as **RPI-RP2**, this might be different if you are not using an RP2040 board.
4. Drag and drop the `.UF2` file you downloaded in step 1 to the `RPI-RP2` boot drive.
5. After a couple of seconds some lights will flash and a new drive will appear in your computer, this time it should be called **CIRCUITPY**.
6. ⚠️ Always eject your device before removing it.
7. Your device is ready to be installed.

The official docs to install CircuitPython can be found [here](https://learn.adafruit.com/adafruit-qt-py-2040/circuitpython)

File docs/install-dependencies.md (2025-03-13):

# Install Dependencies for the Tinker Pod

The official documentation for installing dependencies in CircuitPython can be found [here](https://learn.adafruit.com/welcome-to-circuitpython/circuitpython-libraries).

## Option 1 (easy)

Copy the `lib` directory and its contents from the example or the firmware directory. to the _CIRCUITPY_ directory.

## Option 2 (harder)

Use [this](https://marketplace.visualstudio.com/items?itemName=joedevivo.vscode-circuitpython) extension from Visual Studio Code.

### How to install a dependency

1. Open the _CIRCUITPY_ directory in Visual Studio Code.
2. Use the shortcut `Ctrl+Shift+P` to open the command palette.
3. Type `CircuitPython` and select `CircuitPython: Choose CircuitPython board`.
4. Select the board, in this case `QT PY RP2040`
5. Press `Enter` to confirm the selection.
6. Use the shortcut `Ctrl+Shift+P` to open the command palette.
7. Type `CircuitPython` and select `CircuitPython: Show available libraries`.
8. Type the name of the dependency and select the option that matches the desired library.
9. Press `Enter` to confirm the selection.

## Option 3 (advanced)

Use [CircUp](https://learn.adafruit.com/keep-your-circuitpython-libraries-on-devices-up-to-date-with-circup) to install the dependencies.

1. Install and setup `circup`. Use the official guide, found [here](https://learn.adafruit.com/keep-your-circuitpython-libraries-on-devices-up-to-date-with-circup/install-circup).
2. Open the terminal
3. Use the command `circup install library-name`

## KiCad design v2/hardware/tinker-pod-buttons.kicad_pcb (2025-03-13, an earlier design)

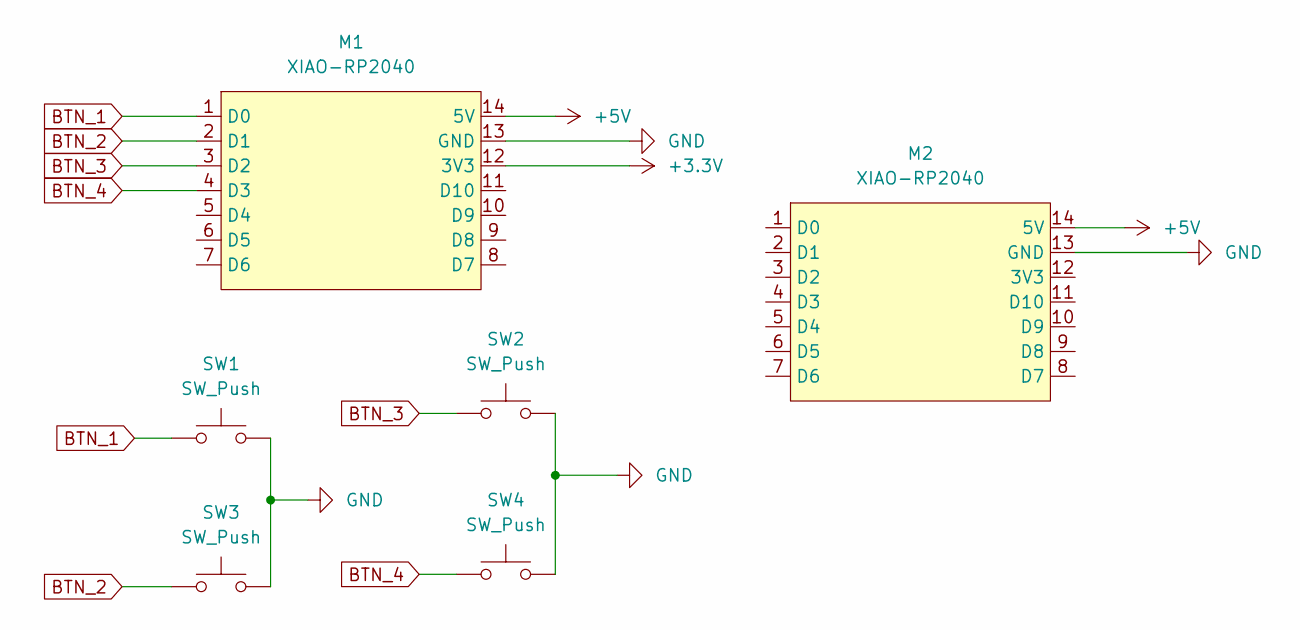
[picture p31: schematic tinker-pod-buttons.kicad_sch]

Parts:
M1: XIAO-RP2040; QTPYRP2040
M2: XIAO-RP2040; XIAO-SAMD21-RP2040-14P-2.54-21X17.8MM (Seeeduino XIAO)
SW1, SW2, SW3, SW4: SW_Push; 3101

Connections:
+3.3V: M1.12 (3V3)
+5V: M1.14 (5V), M2.14 (5V)
BTN_1: M1.1 (D0), SW1.1
BTN_2: M1.2 (D1), SW3.1
BTN_3: M1.3 (D2), SW2.1
BTN_4: M1.4 (D3), SW4.1
GND: M1.13 (GND), M2.13 (3V3), SW1.2, SW2.2, SW3.2, SW4.2

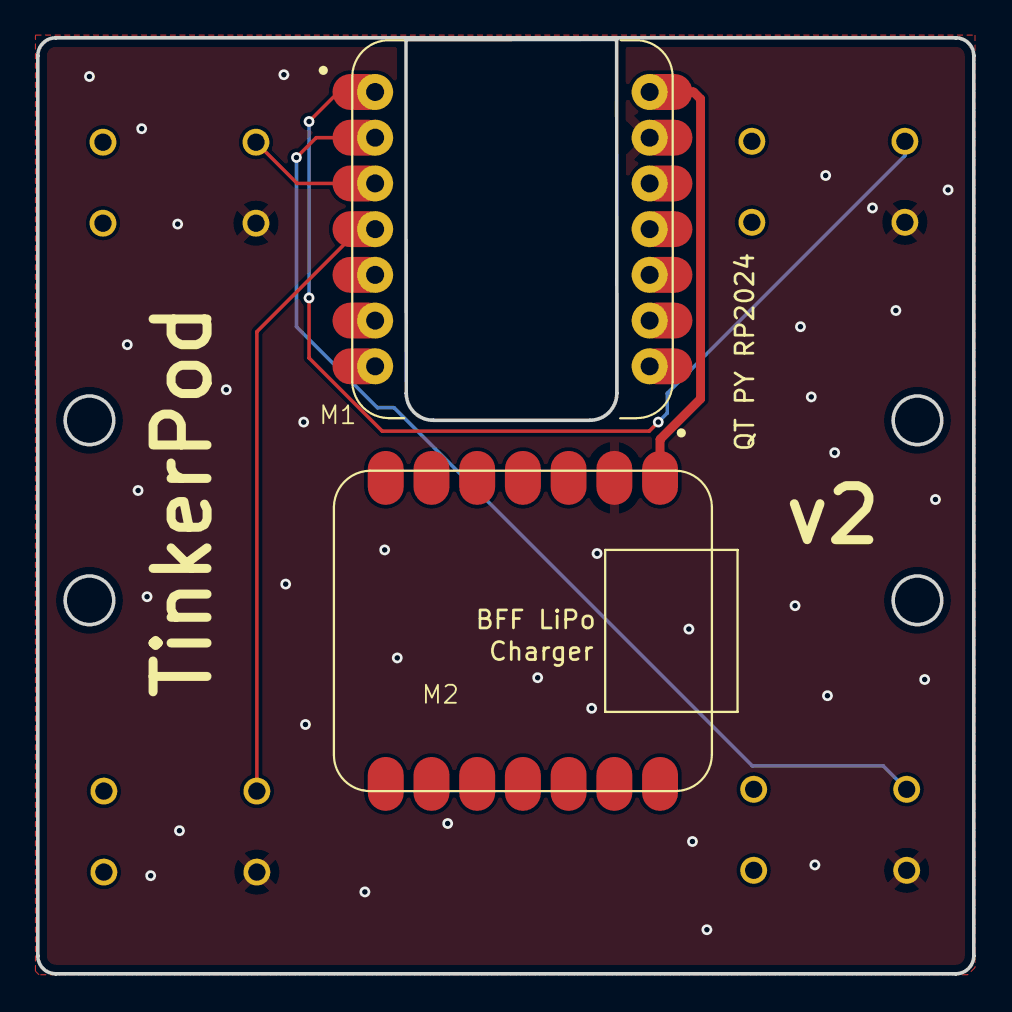
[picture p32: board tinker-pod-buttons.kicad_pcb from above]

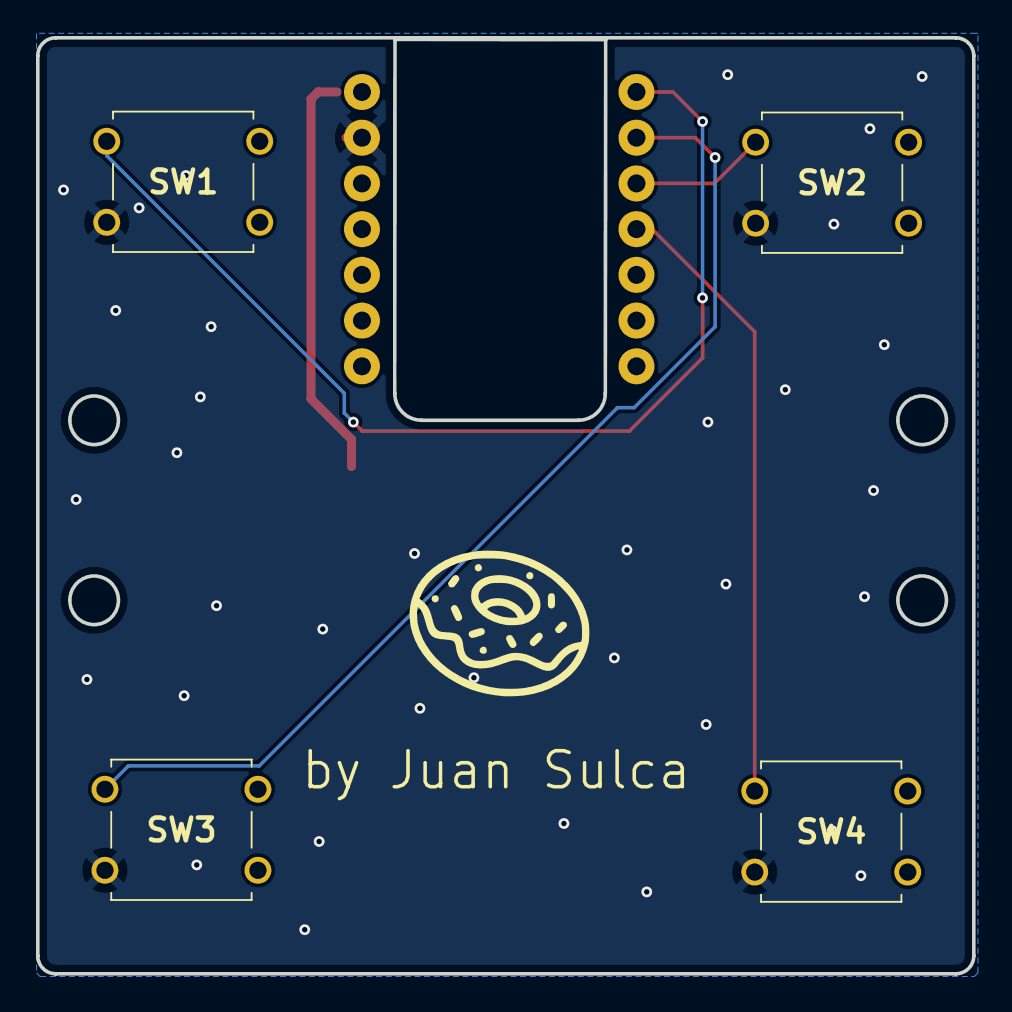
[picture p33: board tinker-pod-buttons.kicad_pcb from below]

Board: 2 copper layers, 52.0 x 52.0 mm, 6 parts (4 on the bottom side), 6 nets.

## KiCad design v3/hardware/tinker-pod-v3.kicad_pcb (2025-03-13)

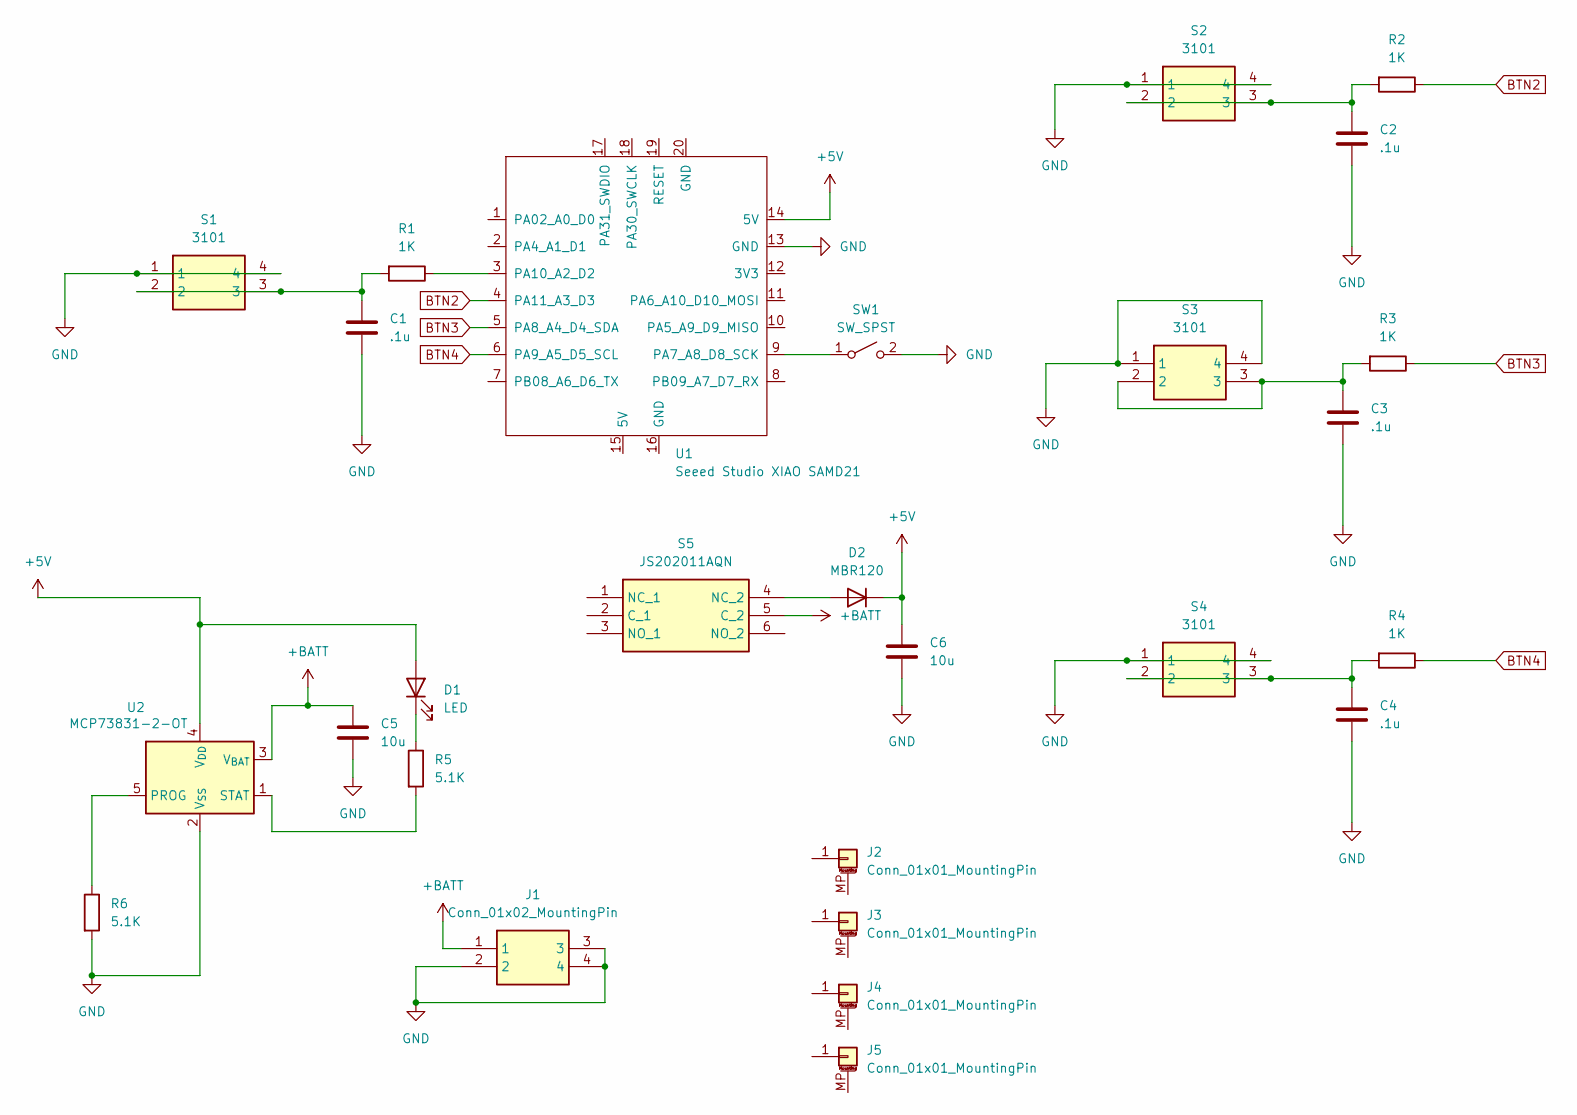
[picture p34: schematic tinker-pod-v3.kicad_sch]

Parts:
C1, C2, C3, C4: .1u; C_1210_3225Metric_Pad1.33x2.70mm_HandSolder
C5, C6: 10u; C_1210_3225Metric_Pad1.33x2.70mm_HandSolder
D1: LED; LED_1206_3216Metric_Pad1.42x1.75mm_HandSolder
D2: MBR120; D_SOD-123
J1: Conn_01x02_MountingPin; B2BPHSM4TBLFSN; Mouser Part Number N/A
J2, J3, J4, J5: Conn_01x01_MountingPin; MountingHole_2.2mm_M2
R1, R2, R3, R4: 1K; R_1206_3216Metric_Pad1.30x1.75mm_HandSolder
R5, R6: 5.1K; R_1206_3216Metric_Pad1.30x1.75mm_HandSolder
S1, S2, S3, S4: 3101; Mouser Part Number 485-3101
S5: JS202011AQN; Mouser Part Number 611-JS202011AQN
SW1: SW_SPST; CP_Radial_D4.0mm_P1.50mm
U1: Seeed Studio XIAO SAMD21; XIAO-SAMD21-RP2040-14P-2.54-21X17.8MM (Seeeduino XIAO)
U2: MCP73831-2-OT; SOT-23-5

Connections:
+5V: C6.1, D1.2 (A), D2.1 (K), U1.14 (5V), U2.4 (V_{DD})
+BATT: C5.1, J1.1, S5.5 (C_2), U2.3 (V_{BAT})
BTN2: R2.1, U1.4 (PA11_A3_D3)
BTN3: R3.1, U1.5 (PA8_A4_D4_SDA)
BTN4: R4.1, U1.6 (PA9_A5_D5_SCL)
GND: C1.2, C2.2, C3.2, C4.2, C5.2, C6.2, J1.2, J1.3, J1.4, R6.2, S1.1, S1.4, S2.1, S2.4, S3.1, S3.4, S4.1, S4.4, SW1.2 (B), U1.13 (GND), U2.2 (V_{SS})
unnamed: C1.1, R1.2, S1.2, S1.3
unnamed: C2.1, R2.2, S2.2, S2.3
unnamed: C3.1, R3.2, S3.2, S3.3
unnamed: C4.1, R4.2, S4.2, S4.3
unnamed: D1.1 (K), R5.1
unnamed: D2.2 (A), S5.4 (NC_2)
unnamed: SW1.1 (A), U1.9 (PA7_A8_D8_SCK)
unnamed: R1.1, U1.3 (PA10_A2_D2)
unnamed: R6.1, U2.5 (PROG)
unnamed: R5.2, U2.1 (STAT)

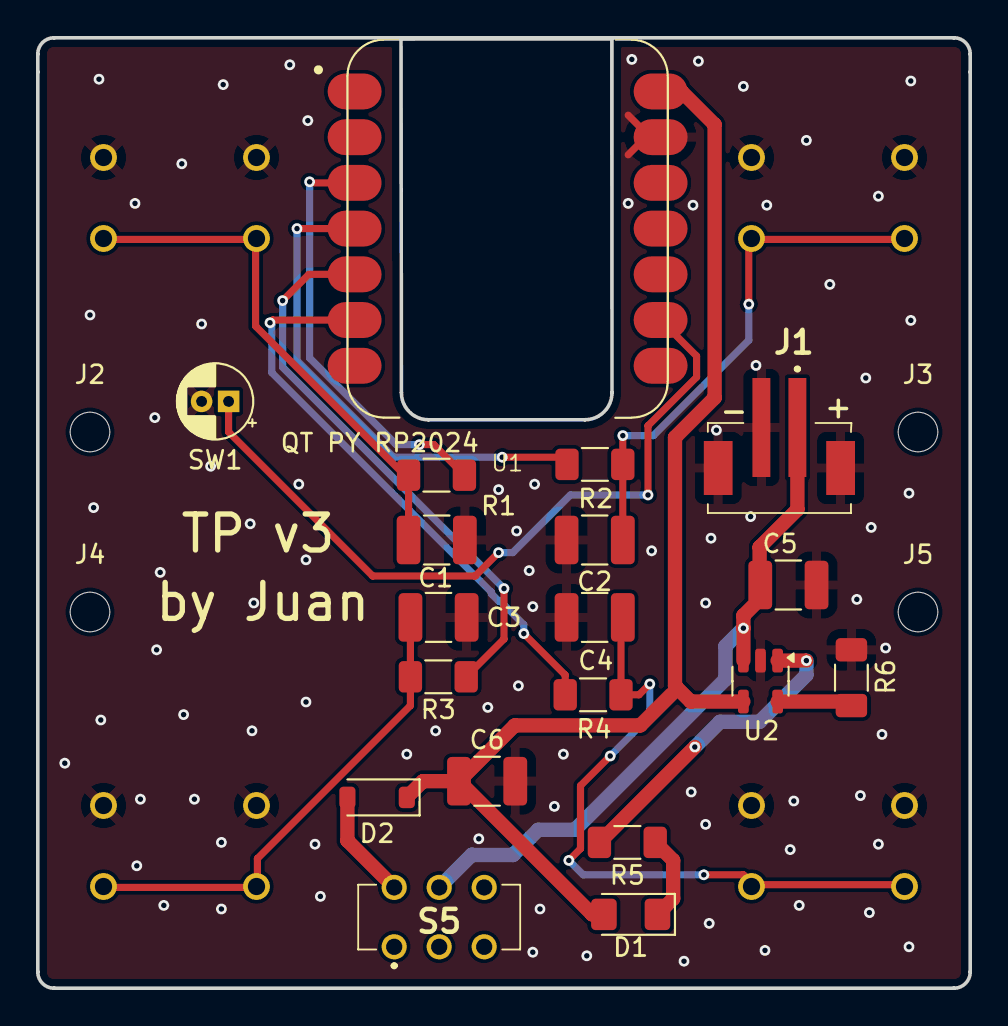
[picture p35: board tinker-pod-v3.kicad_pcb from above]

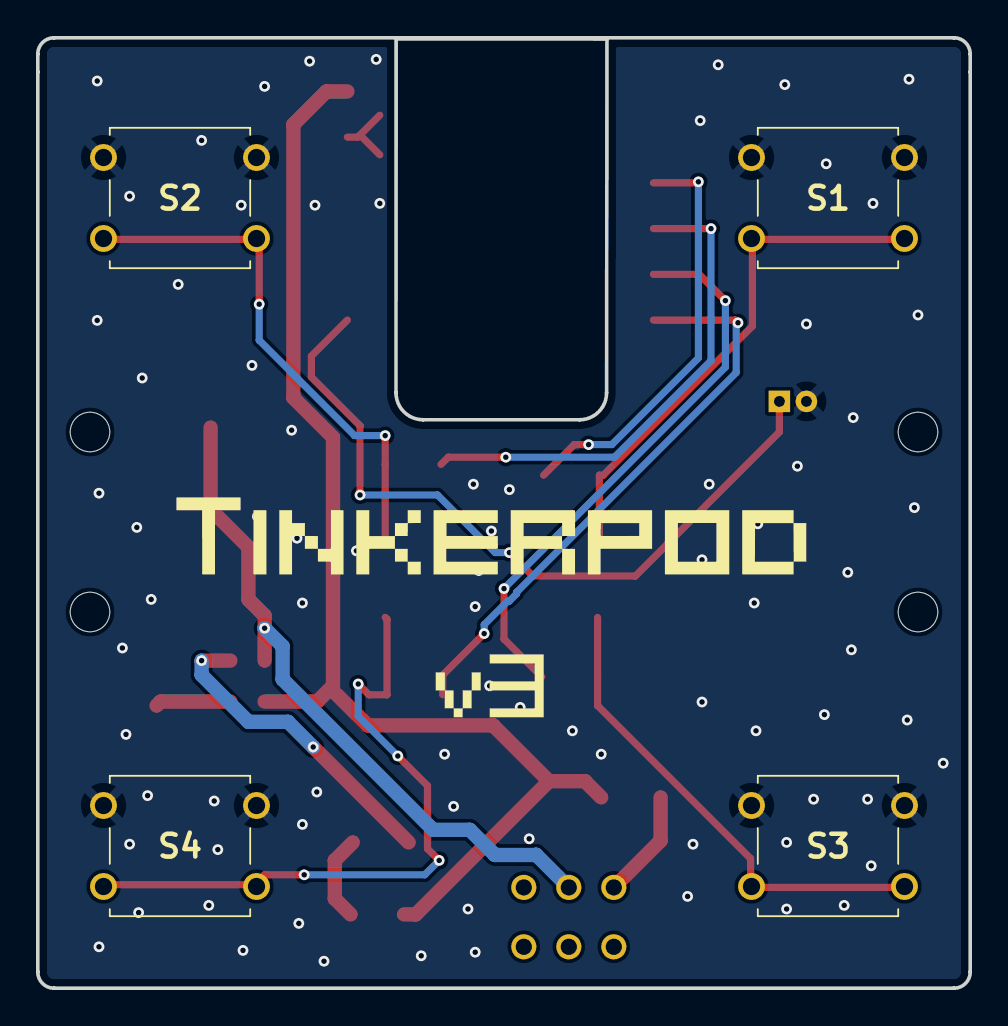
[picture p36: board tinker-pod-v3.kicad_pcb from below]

Board: 2 copper layers, 51.8 x 52.8 mm, 27 parts (4 on the bottom side), 16 nets.

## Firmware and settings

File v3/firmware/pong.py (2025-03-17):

from adafruit_display_shapes.rect import Rect
from adafruit_display_text import label
import terminalio
import time
from displayio import Group
from core import FPS_DELAY, SCREEN_HEIGHT
from base_app import App
from adafruit_ticks import ticks_ms, ticks_diff
from random import choice

font = terminalio.FONT

class Paddle:
  """
  Represents a paddle in the pong game
  """
  def __init__(self, x: int, y: int):
    self.x = x
    self.y = y
    self.width = 4
    self.height = 24
    self.velocity = 0
    # draw paddle as a rectangle
    self.sprite = Rect(self.x, self.y, self.width, self.height, fill=0xEEEEEE, outline=0xEEEEEE)

  def update(self, up: bool, down: bool):
    """
    Update the paddle position and velocity based on the button state
    """
    if up and self.y > 0:
      # move up if the button is pressed and the paddle is not at the top
      self.velocity = -1
    else:
      self.velocity = 0

    if down and self.y < SCREEN_HEIGHT - 1 - self.height:
      # move down if the button is pressed and the paddle is not at the bottom
      self.velocity = 1

    if not up and not down:
      # stop the paddle if no button is pressed
      self.velocity = 0

    # move paddle based on the velocity
    self.y += self.velocity
    # update the sprite y position
    self.sprite.y = self.y

  def reset(self):
    """Reset the paddle position"""
    self.y = 52
    self.sprite.y = self.y

class Puck:
  """
  Represents the puck in the pong game
  """
  def __init__(self, x: int, y: int):
    self.x = x
    self.y = y
    # store the velocity of the puck (vx, vy)
    self.velocity = (1, 0)
    # radius of the puck
    self.r = 4
    # puck sprite
    self.sprite = Rect(self.x, self.y, self.r, self.r, fill=0xDDDDDD, outline=0xDDDDDD)
  def check_collisions(self, paddle_l: Paddle, paddle_r: Paddle):
    """
    Check if the puck collides with the paddles
    """
    if self.x <= paddle_l.x + paddle_l.width/2 and paddle_l.y <= self.y <= paddle_l.y + paddle_l.height:
      # bounce the puck with the left paddle
      y_velocity = self.velocity[1] if paddle_l.velocity == 0 else paddle_l.velocity
      self.velocity = (-self.velocity[0], y_velocity)

    if self.x >= paddle_r.x - paddle_r.width/2 and paddle_r.y <= self.y <= paddle_r.y + paddle_r.height:
      # bounce the puck with the right paddle
      y_velocity = self.velocity[1] if paddle_r.velocity == 0 else paddle_r.velocity
      self.velocity = (-self.velocity[0], y_velocity)

  def update(self):
    """
    update the puck position and velocity
    """
    if self.y < 0 or self.y > SCREEN_HEIGHT - (self.r * 2):
      # bounce the puck with the top and bottom walls
      self.velocity = (self.velocity[0], self.velocity[1] * -1)

    # calculate new position based on the speed
    self.x += self.velocity[0]
    self.y += self.velocity[1]

    # update sprite position
    self.sprite.x = self.x
    self.sprite.y = self.y

  def reset(self):
    """
    Reset the puck position and velocity
    """
    self.x = 64
    self.y = 64
    # velocity is random but always to the left or right
    self.velocity = (choice([1, -1]), 0)


class Score:
  """Represents the score board the game"""
  def __init__(self, x: int, y: int):
    # player scores
    self.p1 = 0
    self.p2 = 0
    # create label
    self.label = label.Label(font, text=f"{self.p1} - {self.p2}", color=0xEEEEEE)
    self.label.x = x
    self.label.y = y

  def update(self, puck: Puck):
    """Update the score based on the puck position"""
    added = False
    if puck.x < 3:
      # add a point to player 2 if the puck reached the left zone
      self.p2 += 1
      added = True
    if puck.x + puck.r > 125:
      # add a point to player 1 if the puck reached the right zone
      self.p1 += 1
      added = True

    if added:
      # update the label text and reset the puck if points were added
      self.label.text = f"{self.p1} - {self.p2}"
      # wait before restarting the game
      time.sleep(1)
      puck.reset()

  def reset(self):
    """Reset the score"""
    self.p1 = 0
    self.p2 = 0
    self.label.text = f"{self.p1} - {self.p2}"

class Pong(App):
  """Pong game application"""
  def __init__(self, root):
    self.splash = Group()
    root.append(self.splash)
    # draw the game board
    self.splash.append(Rect(1, 1, 126, 126, fill=0x000000, outline=0x333333))
    # create and display paddles
    self.left_paddle = Paddle(2, 52)
    self.splash.append(self.left_paddle.sprite)
    self.right_paddle = Paddle(122, 52)
    self.splash.append(self.right_paddle.sprite)
    # create and display the puck
    self.puck = Puck(64, 64)
    self.splash.append(self.puck.sprite)
    # create and display the score board
    self.score = Score(54, 8)
    self.splash.append(self.score.label)
    self.game_over = False # game over state
    # create game over text
    self.game_over_text = label.Label(font, text="Game Over", color=0xEEEEEE)
    self.game_over_text.x = 40
    self.game_over_text.y = 64
    # hide the game over text
    self.game_over_text.hidden = True
    # add the game over text to the view
    self.splash.append(self.game_over_text)

  def run(self, btn_y, btn_x, btn_b, btn_a, shake=None):
    last_update_time = ticks_ms()
    while True:
      now = ticks_ms()

      # game runs at 60 FPS
      if ticks_diff(now, last_update_time) >= FPS_DELAY:
        # update paddle positions
        self.left_paddle.update(not btn_y.value, not btn_b.value)
        self.right_paddle.update(not btn_x.value, not btn_a.value)
        # bounce the puck with the paddles
        self.puck.check_collisions(self.left_paddle, self.right_paddle)
        self.puck.update()
        # update score board
        self.score.update(self.puck)

        if self.score.p1 >= 3 or self.score.p2 >= 3:
          # show game over text if any player reaches 3 points
          self.game_over_text.hidden = False
          while (True):
            # wait for user input
            if not btn_y.value:
              # restart the game
              self.game_over_text.hidden = True
              last_update_time = ticks_ms()
              self.score.reset()
              self.puck.reset()
              self.left_paddle.reset()
              self.right_paddle.reset()
              break
            if not btn_b.value:
              # exit the game
              return

        last_update_time = now

  def cleanup(self, root):
    """Tear down the pong game application"""
    root.remove(self.splash)

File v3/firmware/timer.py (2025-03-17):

import random
import time
from displayio import Group, TileGrid, OnDiskBitmap
from adafruit_display_text import label
from terminalio import FONT
from adafruit_ticks import ticks_ms, ticks_diff
from digitalio import DigitalInOut
from base_app import App

COLS = 8
ROWS = 8
# list of available timers, timer value in seconds
TIMERS = [("30s", 30), ("1m", 60), ("2m", 120), ("3m", 120), ("5m", 300), ("10m", 600), ("15m", 900), ("30m", 1800)]
# Tile mapping
FILLED = 0
UP_ARROW = 1
DOWN_ARROW = 2
GO_BUTTON = 3
X_BUTTON = 4
EMPTY = 5
# colors
LABEL_COLOR = 0xEEEEEE

# preload application sprites
sprite_sheet = OnDiskBitmap("/TP_timer.bmp")

class Timer(App):
  """
  Timer application
  """
  def __init__(self, root):
    self.splash = Group()
    # load sprites into tile grid
    self.sprite = TileGrid(sprite_sheet, pixel_shader=sprite_sheet.pixel_shader, width=COLS, height=ROWS, tile_width=16, tile_height=16, default_tile=EMPTY)
    self.selected = 0
    # create label for the timer duration
    self.timer_duration = label.Label(FONT, text=TIMERS[0][0], color=LABEL_COLOR, scale=3)
    self.timer_duration.x = 42
    self.timer_duration.y = 64
    # display ui elements
    self.splash.append(self.sprite)
    self.splash.append(self.timer_duration)
    root.append(self.splash)

  def run(self, btn_y, btn_x, btn_b, btn_a, shake):
    """
    Run the timer application
    """
    last_update_time = ticks_ms()
    self.show_buttons()

    # application loop
    while True:
      now = ticks_ms()

      #run every 200ms
      if (ticks_diff(now, last_update_time) >= 200):
        if not btn_x.value:
          # increase the timer duration and update label
          self.selected = (self.selected + 1) if self.selected < len(TIMERS) - 1 else self.selected
          self.timer_duration.text = TIMERS[self.selected][0]

        if not btn_a.value:
          # decrease the timer duration and update label
          self.selected = (self.selected - 1) if self.selected > 0 else 0
          self.timer_duration.text = TIMERS[self.selected][0]

        if not btn_y.value:
          # start the countdown
          # hide duration label
          self.timer_duration.hidden = True
          # hide buttons
          self.hide_buttons()
          # create and start the countdown
          countdown = Countdown(self.sprite, TIMERS[self.selected][1])
          countdown.start(btn_b)
          # clear the tile grid
          self.clear_tile_grid()
          # wait to debounce the input
          time.sleep(0.3)
          # show the buttons and duration label
          self.show_buttons()
          self.timer_duration.hidden = False
          continue

        if not btn_b.value:
          # exit the application
          return

        last_update_time = now

  def show_buttons(self):
    """
    Show the button ui sprites on the screen
    """
    self.sprite[1, 1] = GO_BUTTON
    self.sprite[1, 6] = X_BUTTON
    self.sprite[6, 1] = UP_ARROW
    self.sprite[6, 6] = DOWN_ARROW

  def hide_buttons(self):
    """
    Hide the button ui sprites on the screen
    """
    self.sprite[1, 1] = EMPTY
    self.sprite[1, 6] = EMPTY
    self.sprite[6, 1] = EMPTY
    self.sprite[6, 6] = EMPTY

  def clear_tile_grid(self):
    """
    Clear the tile grid
    """
    # traverse the tile grid and set each tile to EMPTY
    for i in range(COLS):
      for j in range(ROWS):
        self.sprite[i, j] = EMPTY

  def cleanup(self, root):
    """
    Tear down the application
    """
    root.remove(self.splash)

class Countdown:
  """
  Countdown tracker class
  """
  def __init__(self, tile_grid: TileGrid, duration: int):
    self.sprite = tile_grid
    # set how often a tile should appear in milliseconds
    self.update_delta = (duration* 1000) // (COLS * ROWS)

  def start(self, stop_btn: DigitalInOut):
    """Initialize or restart the countdown."""
    last_update = ticks_ms()
    # create a set of empty tiles [1, 2, 3, ...]
    empty_tiles = set(range(COLS * ROWS))
    # initialize counters for the flash animation
    flash_count = 0
    flash_timer = 0
    ended = False
    # show the tile grid
    self.sprite.hidden = False

    # countdown loop
    while True:
      if not stop_btn.value:
        # stop the countdown if stop button is pressed
        return
      now = ticks_ms()

      # run every update_delta milliseconds
      if not ended and ticks_diff(now, last_update) >= self.update_delta:
        # pick random tile from the set of empty tiles
        i = random.choice(list(empty_tiles))
        # remove the selected tile
        empty_tiles.remove(i)
        # calculate the x, y position of the tile based on the index
        x = i // COLS
        y = i % ROWS
        # set the tile to filled sprite
        self.sprite[x, y] = FILLED

        last_update = now

        if len(empty_tiles) == 0:
          # end the tiles sequence and start the flash animation
          ended = True
          flash_timer = last_update

      # show the flashing animation after countdown is over
      if ended:
        # toggle the flash animation every 600ms
        if ticks_diff(now, flash_timer) >= 600:
          # initialize flash timer
          flash_timer = now
          if flash_count == 0:
            # draw arrow share on before the first flash
            self.draw_arrow()
          flash_count += 1
          self.toggle_flash()

          if flash_count > 6:
            # end the flashing animation after 5 flashes
            self.sprite.hidden = False
            # end the countdown
            return

  def toggle_flash(self):
    """
    Toggle hiding the tile grid
    """
    self.sprite.hidden = not self.sprite.hidden

  def draw_arrow(self):
    """
    Draw the arrow shape on the tile grid
    """
    self.sprite[0, 4] = EMPTY
    self.sprite[0, 5] = EMPTY
    self.sprite[0, 6] = EMPTY
    self.sprite[0, 7] = EMPTY
    self.sprite[1, 7] = EMPTY
    self.sprite[2, 7] = EMPTY
    self.sprite[3, 7] = EMPTY
    self.sprite[1, 6] = EMPTY
    self.sprite[2, 5] = EMPTY
    self.sprite[3, 4] = EMPTY

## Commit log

2024-08-08 Added case STL files
    [Bottom_case_v6.stl, Top_case_v6.stl]
2024-09-19 Updated stl case designs to center usb port
    [Bottom_case_v6.stl, Bottom_case_v8.stl, Top_case_v6.stl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]
2025-03-09 updated project structure
    [Bottom_case_v8.stl, Top_case_v8.stl]
2025-03-09 Added lib folder to examples
    [Bottom_case_v8.stl, Top_case_v8.stl]
2025-03-09 Updated v1 wiring diagram
2025-03-10 Added v2 assembly guide
2025-03-13 Added hardware projects to v2 and v3
    [tinker-pod-buttons.kicad_pcb, tinker-pod-buttons.kicad_sch, tinker-pod-buttons.step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]
2025-03-13 Updated v1 assembly guide
2025-03-27 Uploaded CAD files for V1 and V3
    [Bottom_case_v8.stl, TP_v1_case.3mf, TP_v3_case.3mf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]
2025-03-27 Added case files v2
    [TP_v2_case.3mf, TP_v2_case.f3z]
